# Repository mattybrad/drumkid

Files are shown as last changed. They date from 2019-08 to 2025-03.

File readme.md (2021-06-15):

# DrumKid
## Lo-fi aleatoric Arduino drum machine

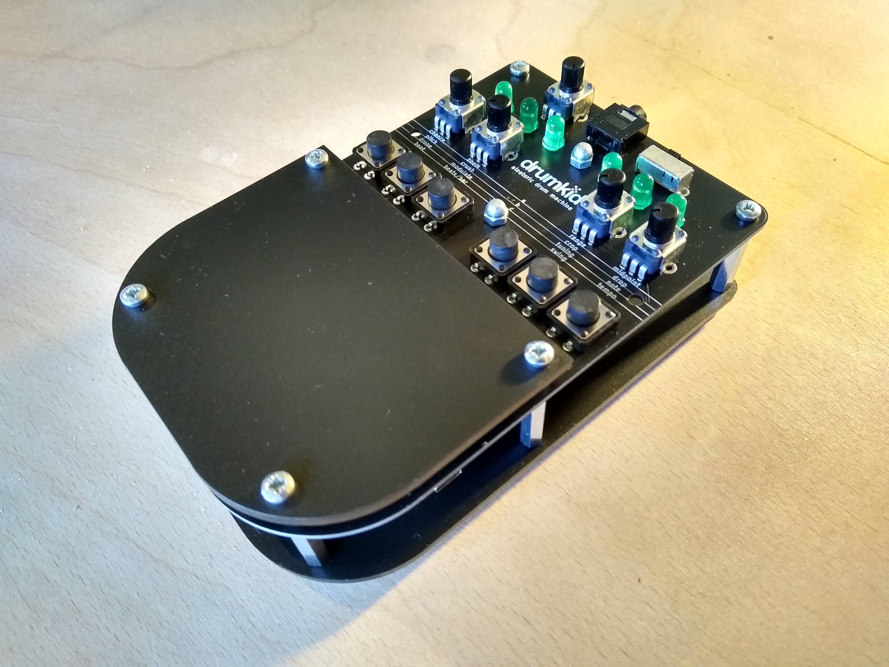
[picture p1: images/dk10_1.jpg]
DrumKid DrumKid (V10)


### Concept
A drum machine which generates rhythms using probability. Imagine a traditional step-based drum machine, but where various dice are rolled for each step, with the resulting numbers used to determine the behaviour of the beat.

### Buy Drumkid
You can buy Drumkid fully assembled or as a kit from <mattbradshawdesign.com>

### Setup
DrumKid is based around an Arduino Nano, and coded using the Arduino IDE. Audio is produced by the Mozzi library. You can build a version of DrumKid using an Arduino, a breadboard, and standard electronic components, or you can build/buy the "full" version described below.

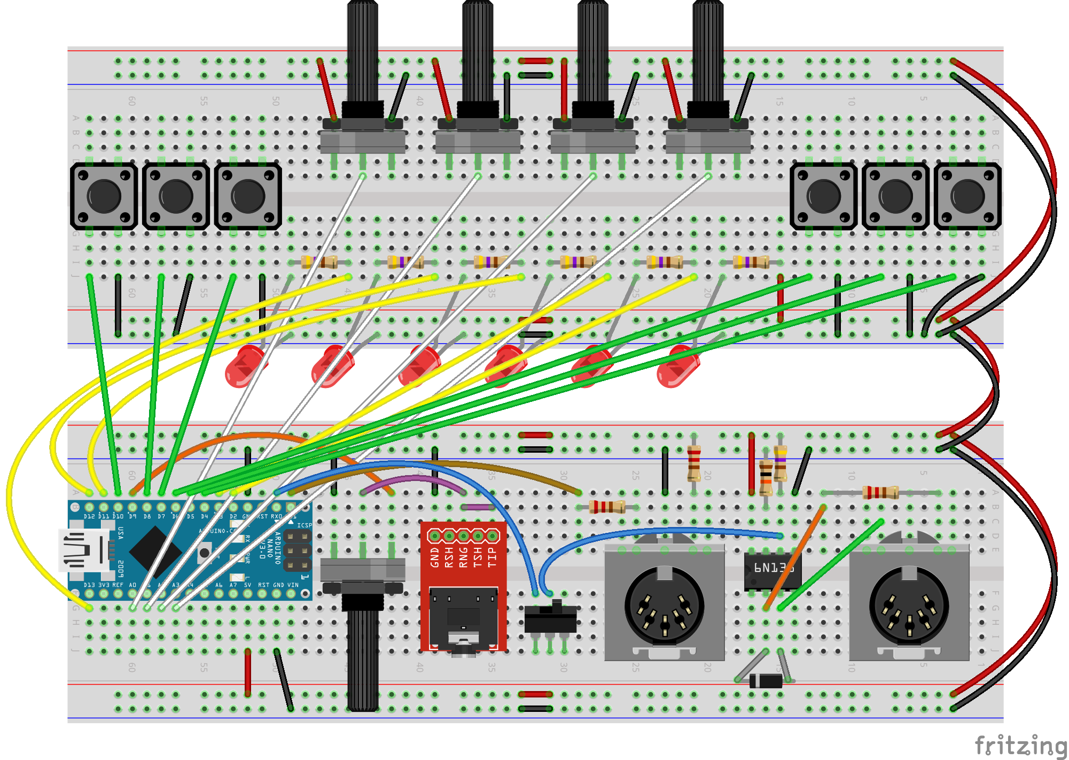
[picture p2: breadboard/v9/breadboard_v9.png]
Breadboard layout Breadboard layout (V9)


### Design
DrumKid is a portable, handheld, battery-powered instrument with a minimalist design. It consists of a PCB (printed circuit board) for the front panel, featuring knobs, buttons, LEDs, a power switch and a headphone/line output. The electronics are protected/enclosed by two laser-cut acrylic pieces and six metal standoffs.

### Open Source
This project is almost entirely open source. The code, breadboard layout, schematics, Gerber (PCB) files, and laser-cutter files are all included in the repository, with the aim of making this project easy to duplicate and adapt. Please note that the project depends on the Mozzi library, which is released under a Creative Commons non-commercial licence. I have used it here with kind permission from its creator, but please be aware that if you create a commercial product using this code, you will need to request permission from him. Go to <https://sensorium.github.io/Mozzi/> for more details.

### Versions
Versions 1-3 were early prototypes.

Version 4 was the first successful working design, with full code, schematics, Gerbers, etc available on GitHub.

Version 5 contained various PCB errors and has been superseded.

Versions 6 onwards were used in the final product, with version 10 being the latest at the time of writing.

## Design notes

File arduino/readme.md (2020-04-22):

# DrumKid Arduino code

While developing DrumKid, each new PCB version pretty much required its own new version of the code. Now that the project is nearing completion, I've reorganised the code as follows:

0.4 - this was the code for the V4 PCB
0.5 - this was the code for the V5 PCB
1.0 - this is the code for the V6 onwards

Unless you've got an old version of DrumKid, you should just refer to the latest version.

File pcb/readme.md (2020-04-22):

# PCB files

DrumKid is designed using KiCad. You can edit the KiCad files to produce a custom DrumKid PCB, or just use the Gerber files provided to order a DrumKid PCB from a manufacturer. The latest working, tested PCB is V6. V7 is coming soon with (very) minor revisions, and V8 might involve some surface-mount components because I've just learnt how to design/order pre-assembled boards.

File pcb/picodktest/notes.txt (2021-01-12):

change output resistors from 1K to 220R
label possible LED resistor values
include info about unused hacker pins

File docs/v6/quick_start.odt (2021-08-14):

Drumkid quick start guide

1) Insert batteries - unscrew the 6 thumbscrews on the back of Drumkid (you don't need a screwdriver), remove the back plate, and insert 3 AA batteries (rechargeable or regular). Alternatively, connect a USB mini cable to power the device. Carefully re-tighten the thumbscrews.

2) Connect audio - plug 3.5mm audio cable (mono or stereo) or a pair of headphones into the audio output.

3) Turn on and test - slide the power switch (top right on the front panel) from "0" to "1". The lights should flash briefly in a random pattern. Now press the "start/stop" button. The lights should flash in time to a drum beat, which you should be able to hear through the headphones.

4) Get to know the controls - try turning the "chance" control (the knob on the left) and the “midpoint” control (on the right). As long as “midpoint” is set high enough, you should hear more random drum hits as the “chance” parameter increases. Now try adjusting “zoom” and “range” to see what they do.

5) Try other parameters/effects - press the "B" button to switch to the second group of parameters. The knobs will now perform different functions. Try the left knob again - it will now change the pitch of the samples or make them play in reverse.

6) Randomise all the parameters - try pressing the A, B and D buttons simultaneously to generate a new random beat. Use these as a starting point to explore the different parameters.

7) Read the full manual online at mattbradshawdesign.com for detailed information about the different parameters, MIDI control, saving/loading sessions, troubleshooting, hacking Drumkid, etc.

If you have any problems, feel free to email me at

matthewloydbradshaw@gmail.com

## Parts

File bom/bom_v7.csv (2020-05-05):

Item | Quantity | Notes
DrumKid PCB | 1 | Not needed for breadboard version
Battery box (3xAA) | 1 | Not needed for breadboard version
Female header, 15x1 | 2 | Not needed for breadboard version
MIDI socket | 2
EG1206 slide switch (SPDT) | 2 | Not needed for breadboard version
DIP socket (8 pin) | 1 | Not needed for breadboard version
6N138 optoisolator | 1
1N5817 diode | 1
1N4148 diode | 1
Resistor (220) | 3
Resistor (470) | 1
Resistor (680) | 6
Resistor (10k) | 1
RK09K Potentiometer (10k linear taper) | 5 | Use breadboard compatible 10k pots for breadboard
LED (standard 5mm) | 6
Tayda A-853 stereo jack socket | 1 | Use breadboard-friendly 3.5mm jack socket for breadboard (or solder wires/header to standard 3.5mm socket)
12mm tactile push button (Wurth 430476085716) | 6
Electrolytic capacitor (470uF) | 2
Arduino Nano or compatible | 1
Laser-cut front panel cover (acrylic) | 1 | Not needed for breadboard version
Laser-cut rear panel (acrylic) | 1 | Not needed for breadboard version
M3 thumb screw (nylon, 10mm) | 8 | Not needed for breadboard version
M3 machine screw (6mm, pan head) | 4 | Not needed for breadboard version
M3 machine screw (10mm, pan head) | 2 | Not needed for breadboard version
M3 machine screw (10mm, countersunk head) | 2 | Not needed for breadboard version
M3 dome nut | 2 | Not needed for breadboard version
M3 hex nut | 4 | Not needed for breadboard version
M3xM3 standoff (female/female, 25mm) | 6 | Not needed for breadboard version
M3xM3 standoff (male/female, 5mm) | 4 | Not needed for breadboard version

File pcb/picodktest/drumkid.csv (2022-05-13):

Comment | Designator | Footprint | LCSC
Arduino_Nano_v3.x | A1 | Module:Arduino_Nano_WithMountingHoles
Battery | BT1 | Connector_Wire:SolderWirePad_1x02_P5.08mm_Drill1.5mm
470uF | C1,C3 | Capacitor_THT:CP_Radial_D6.3mm_P2.50mm
100nF | C2 | Capacitor_SMD:C_0402_1005Metric | C1525
22uF | C5 | Capacitor_SMD:C_0603_1608Metric | C59461
LED | D1,D2,D3,D4,D5,D6 | drumkidcustom:LED_D5.0mm
1N4148 | D7 | Diode_SMD:D_SOD-123 | C81598
1N5817 | D8 | Diode_SMD:D_SOD-123 | C727113
MountingHole | H1,H2,H3,H4,H5,H6,H7,H8,H9,H10 | drumkidcustom:MountingHole_3.2mm_M3
DIN-5_180degree | J1,J2 | drumkidcustom:MIDI_DIN5
Conn_01x15 | J10,J11 | Connector_PinHeader_2.54mm:PinHeader_1x15_P2.54mm_Vertical
Conn_01x05 | J12,J14 | Connector_PinSocket_2.54mm:PinSocket_1x05_P2.54mm_Vertical
Conn_01x15 | J3,J4 | Connector_PinSocket_2.54mm:PinSocket_1x15_P2.54mm_Vertical
Conn_01x10 | J5,J8 | Connector_PinSocket_2.54mm:PinSocket_1x10_P2.54mm_Vertical
Conn_01x10 | J6,J7 | Connector_PinHeader_2.54mm:PinHeader_1x10_P2.54mm_Vertical
AudioJack3_Ground_Switch | J9,J13,J15 | drumkidcustom:Tayda_3.5mm_stereo_TRS_jack_A-853
680 | R1,R2,R3,R4,R5,R6 | Resistor_SMD:R_0805_2012Metric | C17798
220 | R7,R10,R11,R12,R13 | Resistor_SMD:R_0805_2012Metric | C17557
270 | R14 | Resistor_SMD:R_0805_2012Metric | C17590
680 | R15 | Resistor_THT:R_Axial_DIN0207_L6.3mm_D2.5mm_P7.62mm_Horizontal
10k | R8 | Resistor_SMD:R_0805_2012Metric | C17414
470 | R9 | Resistor_SMD:R_0805_2012Metric | C17710
R_POT | RV1,RV2,RV3,RV4 | drumkidcustom:Potentiometer_Alps_RK09K_Single_Vertical
10k | RV5 | drumkidcustom:Potentiometer_Alps_RK09K_Single_Vertical
SW_SPDT | SW7,SW8 | drumkidcustom:EG1206
drumkid_logo | U2,U3 | drumkidcustom:drumkid_logo

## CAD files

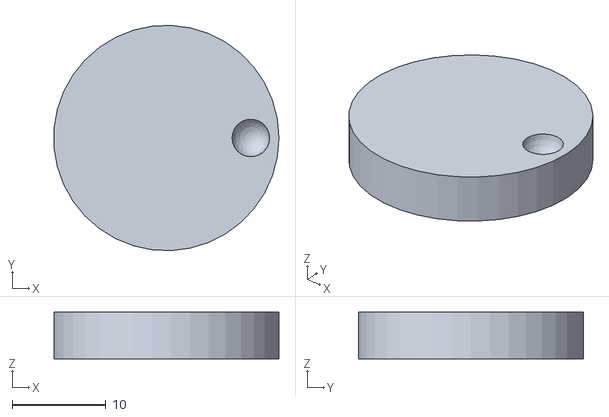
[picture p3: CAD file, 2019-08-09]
case/drumkid_knob.stl
24.0 x 24.0 x 5.00

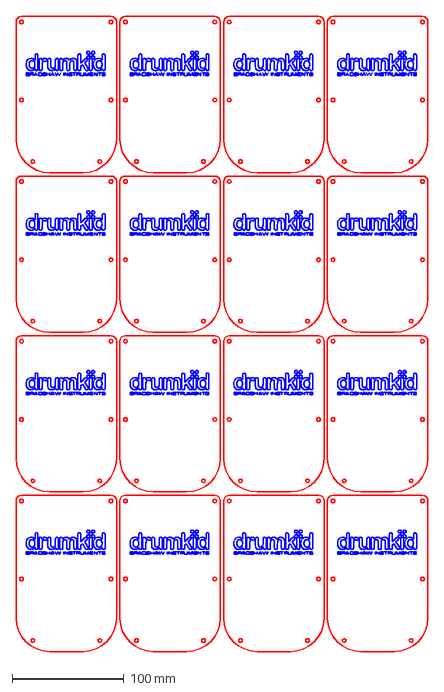
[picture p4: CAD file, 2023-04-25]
case/v6/drumkid laser parts 400x600 with bradshaw instruments text.dxf
369.0 x 569.0 mm

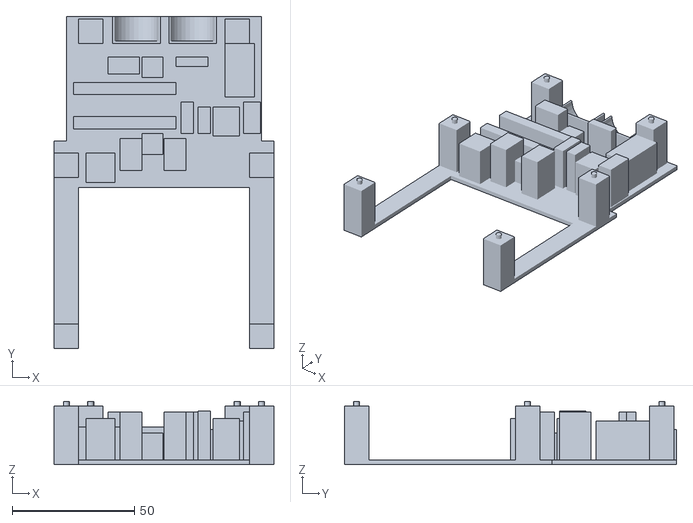
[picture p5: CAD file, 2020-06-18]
misc/jig/jig2.stl
90.0 x 136.0 x 26.0

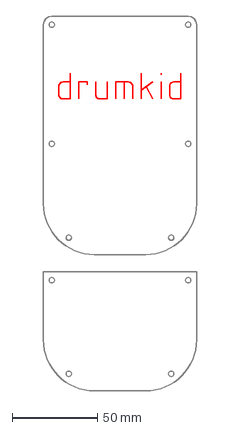
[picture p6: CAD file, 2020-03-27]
v6/case/drumkid laser parts.dxf
90.0 x 220.0 mm

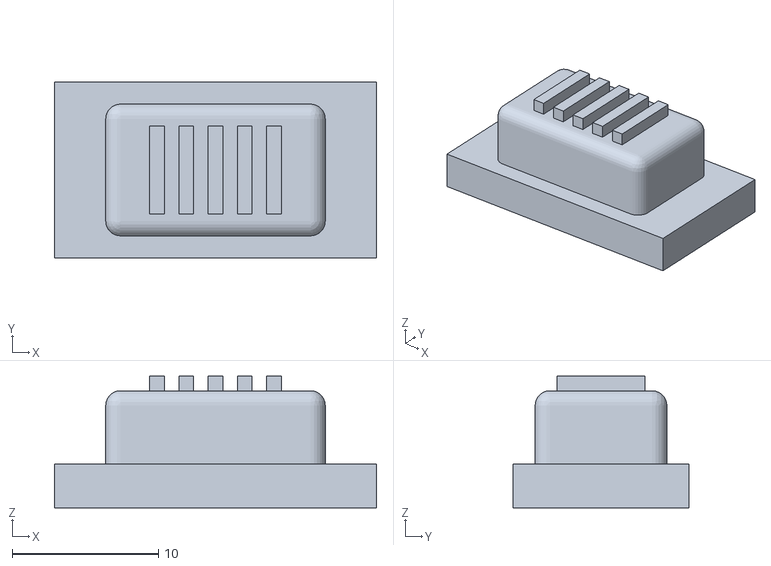
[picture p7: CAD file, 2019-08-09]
case/drumkid_switch.stl
22.0 x 12.0 x 9.00

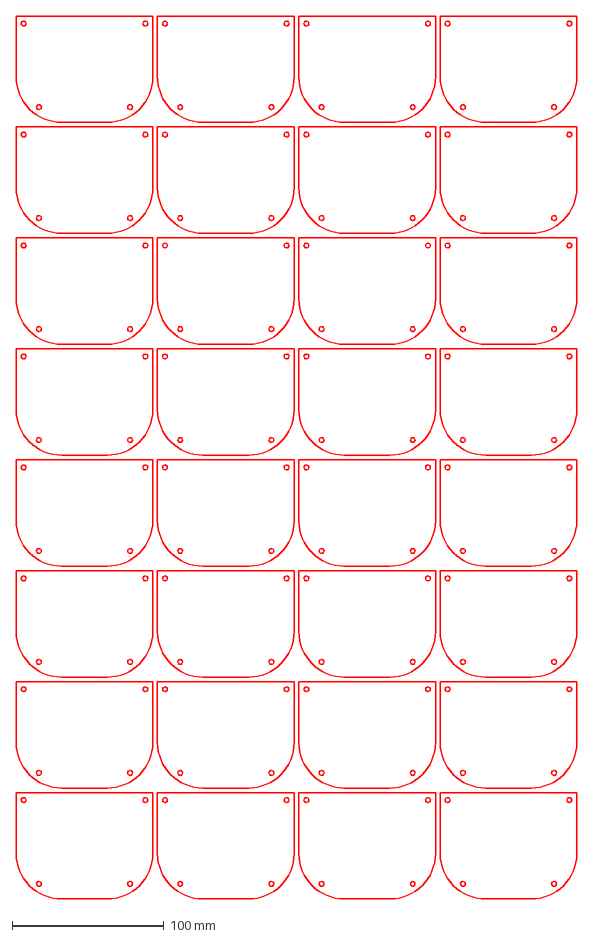
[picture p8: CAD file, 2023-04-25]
case/v6/drumkid front panel 400x600.dxf
369.0 x 581.0 mm

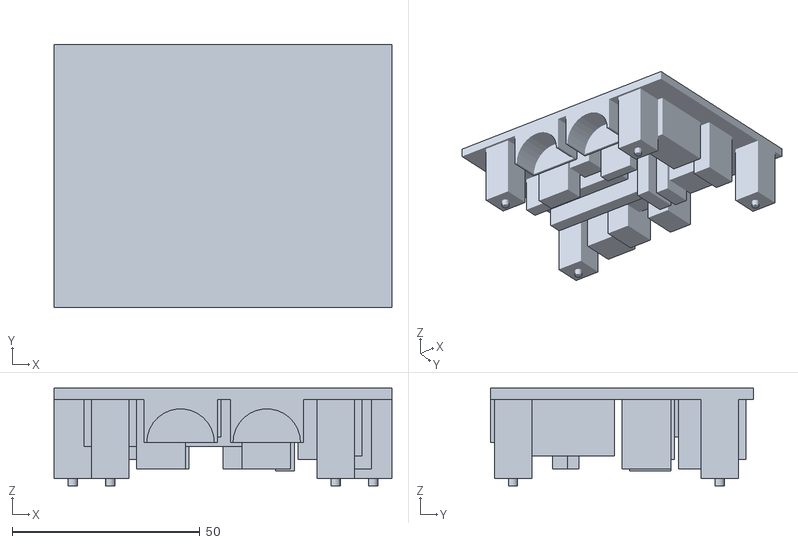
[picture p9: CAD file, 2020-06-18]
misc/jig/jig7.stl
90.0 x 70.0 x 26.0

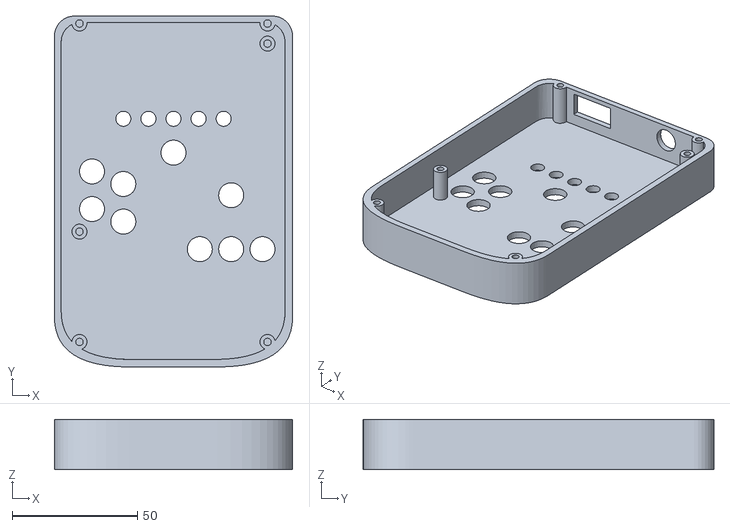
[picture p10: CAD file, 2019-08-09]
case/drumkid_case_top.stl
95.0 x 140.0 x 20.0

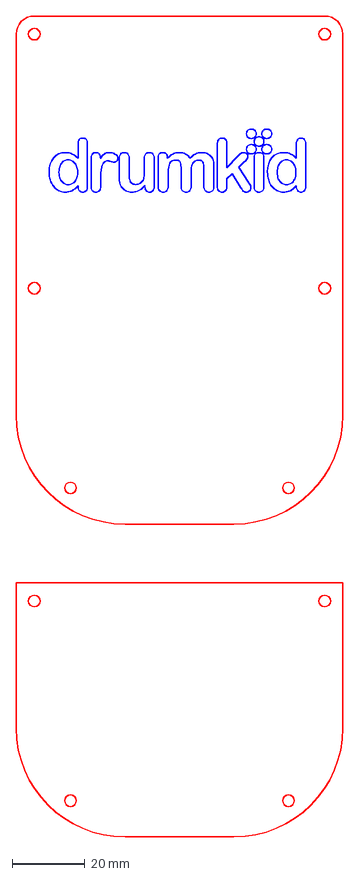
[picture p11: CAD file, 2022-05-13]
case/v6/drumkid laser parts april 22.dxf
90.0 x 226.2 mm

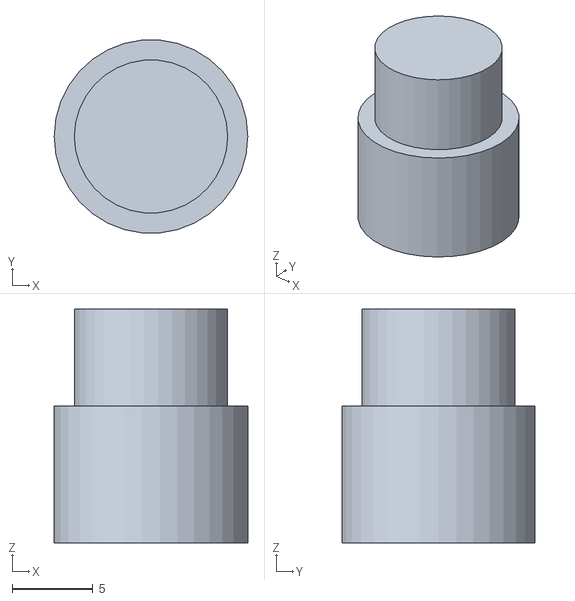
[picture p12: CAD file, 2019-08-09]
case/drumkid_button.stl
12.0 x 11.9 x 14.5

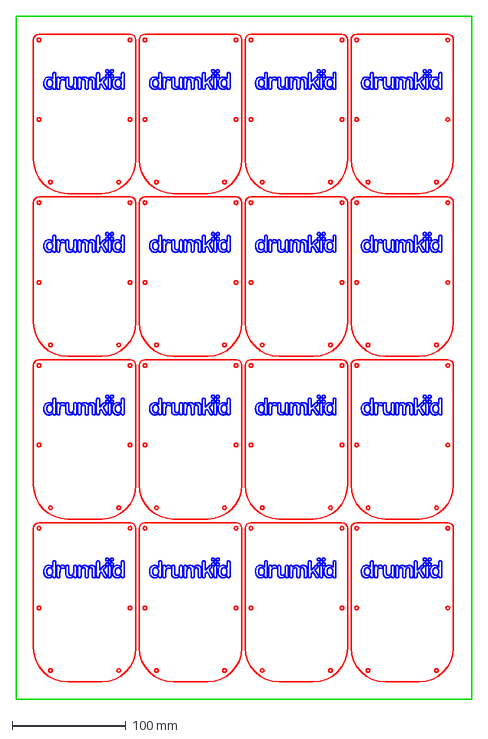
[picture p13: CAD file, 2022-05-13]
case/v6/drumkid laser parts 400x600 engrave only.dxf
400.0 x 600.0 mm

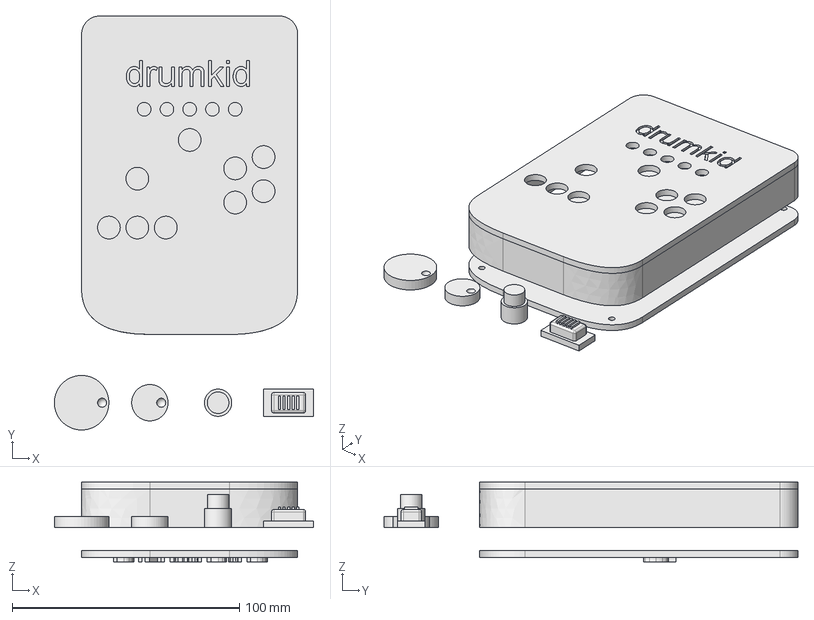
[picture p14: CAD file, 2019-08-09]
case/drumkid_case_1.FCStd
114.0 x 182.0 x 35.0 mm
middle x
bottom001
top with pcb mounts

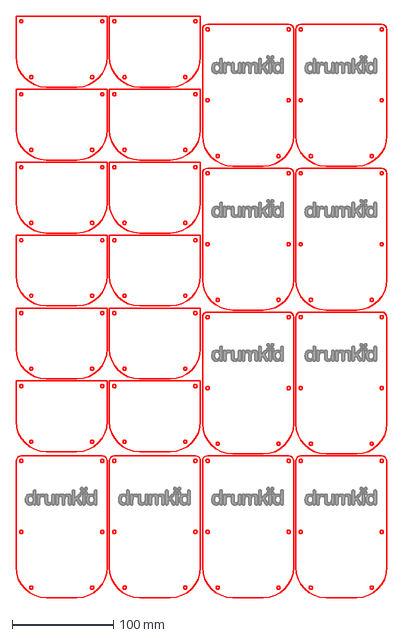
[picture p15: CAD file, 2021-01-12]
case/v6/drumkid laser parts 400x600.dxf
366.0 x 574.0 mm

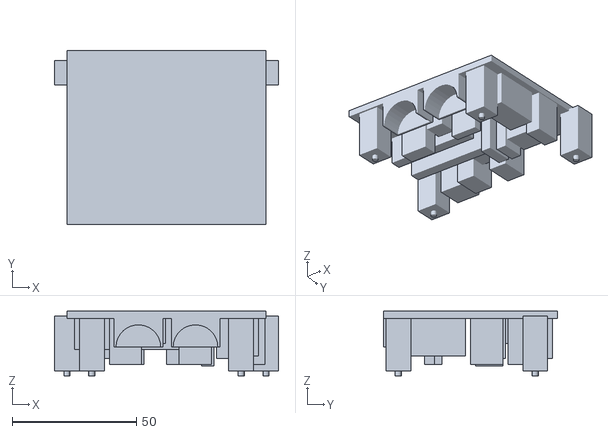
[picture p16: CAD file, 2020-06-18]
misc/jig/jig4.stl
90.0 x 70.0 x 26.0

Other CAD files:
misc/jig/jig6.stl
misc/jig/jig8.stl
case/drumkid_v3_cover.stl
case/v6/drumkid laser parts.dxf
case/drumkid cover laser 1.dxf
case/drumkid cover laser 2.dxf
case/drumkid laser parts v2.dxf
case/drumkid_case_bottom.stl
case/drumkid_knob_small.stl
case/v3 cover.FCStd
case/v4/archive/drumkid cover laser 1.dxf
case/v4/archive/drumkid cover laser 2.dxf
case/v4/archive/drumkid laser parts.dxf
case/v4/archive/drumkid_case_bottom.stl
case/v4/archive/drumkid_knob_small.stl
case/v4/archive/drumkid_v3_cover.stl
case/v4/archive/v3 cover.FCStd
case/v4/drumkid laser parts.dxf
case/v6/drumkid laser parts 600x600.dxf
misc/jig/jig.stl
misc/jig/jig3.stl
misc/jig/jig5.stl
misc/jig/jig9.stl
misc/jig/jig_underside.FCStd
misc/jig/testtri.ply

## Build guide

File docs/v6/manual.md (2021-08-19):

# DrumKid manual (V1.2)
## Introduction
Welcome to the DrumKid manual! DrumKid is a musical instrument that creates rhythms using random numbers. To get started with DrumKid, unscrew the six screws on the back of the unit (you should be able to do this by hand), and carefully remove the back plate. Insert three AA batteries (you can use rechargeable or single-use), replace the back plate, and tighten the screws. Slide the power switch to "on" - you should see the lights flash briefly. After this, DrumKid is ready to use. Plug some headphones or a 3.5mm stereo* aux cable into the socket, and start playing. If you would prefer not to use batteries, you can also power DrumKid by connecting a USB mini cable to the socket recessed on the right hand side of the device.

\* On newer DrumKid models (V8 or later) you can also use a mono 3.5mm cable, but this will not work on older models
## Philosophy
DrumKid is designed around a very basic computer chip with limited memory and processing power. My idea was to squeeze as much cool sound out of this chip as possible, but it has its limits. Rather than try and hide from these limits, I decided to embrace them. This means that it is absolutely possible to make horrible, distorted, broken noises using DrumKid. Some of these horrible noises will sound cool, others will not. DrumKid is a playable instrument like any other - experiment with it and see what happens.
## Demo videos and resources
You can find demo videos and other resources at https://www.mattbradshawdesign.com/projects/drumkid, or more technical info (source code, schematics, etc) at https://github.com/mattybrad/drumkid.
## Basic functions
DrumKid has six buttons and four knobs. The basic functions are as follows:
 - Press the start/stop button to start or stop the rhythm
 - Press buttons A/B/C/D to select different knob functions (see table below)
 - Turn any of the four knobs to alter the parameters in the current selected group (see table below)
 - Tap the tap tempo button repeatedly to set the tempo
 - Press buttons A+B together to load a session, then choose which session to load by pressing any of the buttons (or press multiple buttons together to cancel)
 - Press buttons C+D together to save a session, then choose which slot to save your session in by pressing any of the buttons (or press multiple buttons together to cancel)
 - Press buttons B+C together to change the current active memory bank, then choose a specific memory bank by pressing any of the buttons
## Other functions
DrumKid has a few extra hidden functions:
- Press buttons A+B+C together to reset your beat to default values. This will not affect any saved beats.
- Press buttons A+B+D together to generate a random beat. This will also not affect any saved beats.
- Press buttons B+C+D together to enter the MIDI settings menu (more details in the MIDI section of the manual)
## Presets
In the aleatoric spirit of DrumKid, all 36 sessions stored when you first use the instrument are randomly generated when DrumKid is built. Try loading a few of them to get a feel for what DrumKid can do.
## Parameters
There are 16 different parameters which can be adjusted on DrumKid, split into four groups, with each group's four parameters controlled by the four knobs. The parameters are grouped as follows:

### Group A (randomness)
 1. Chance
 2. Zoom
 3. Range
 4. Midpoint
### Group B (effects)
 1. Pitch
 2. Crush
 3. Crop
 4. Drop
### Group C (drone)
 1. Drone
 2. Modulate
 3. Tuning
 4. Note
### Group D (rhythm)
 1. Beat
 2. Beats/bar (time signature)
 3. Swing
 4. Tempo

You can try out each parameter by starting a rhythm (using the start/stop button), then selecting a group and turning the different knobs. For example, try selecting group B (by pressing the B button) then turning the first knob, which will now control "pitch". You should hear the sound change. Below are descriptions of exactly what each parameter does, and how it can be used.

**Chance** - The probability of extra drum hits being generated. At zero, the beat will be completely unchanged, while for higher values there will be lots of extra events, usually creating a busier, messier beat. This can be used in conjunction with zoom, midpoint, and range to create drum fills that transition organically from a simple beat.

**Zoom** - Chooses which subdivision of the beat should be affected by the randomly generated extra hits. When zoom is at zero, beats will only be generated for "whole notes" (i.e. the first beat of the bar). Higher values will affect half notes, quarter notes, eighth notes, and so on. A medium value is a good place to start for zoom, but turning it up can make a beat or fill sound more "urgent". Some of the smaller subdivisions will vary depending on the current "swing" setting.

**Range** - This is the range of velocities which will be assigned to the random hits, and works in conjunction with "midpoint" (see below). For all the random hits to have the same velocity as each other, keep this value at zero. For a wide range of velocities, turn this up high.

**Midpoint** - This is the average velocity of the randomly generated hits, and works in conjunction with "range". Note that this control does allow negative values (below halfway). If you set the midpoint to maximum and have range set at zero, all the randomly generated hits will be at max velocity. Conversely, if you set it at zero, some hits will be muted. Setting it somewhere in the middle (with non-zero range) will add some random hits while reducing the volume of others. Try keeping midpoint at a three-quarters setting to add a bustling undercurrent to your beat, or turn it up briefly to create a drum fill.

**Pitch** - Alters the playback speed of the samples. Will play samples backwards if you turn the knob below halfway.

**Crush** - Reduces the number of bits used to calculate the audio output, creating a digital distortion effect. Higher values are clean, lower values are more distorted (fewer bits).

**Crop** - Crops the end of the samples, creating a staccato effect. Lower values are more cropped.

**Drop** - This control mutes some or all of the drum channels, allowing you to quickly "drop" everything except the hi-hat and snare, for example, or only retain the kick drum. Broadly, this control has "treble-y" channels at one end and "bass-y" channels at the other. The setting corresponding to all the channels being audible is somewhere in the middle.

**Drone** - DrumKid generates a drone which can be mixed with the drum sounds. The "drone" parameter controls the amount of raw drone signal added to the mix. Turning to the left adds a single tone, while turning to the right adds two tones, a fifth apart. A halfway value mutes the drone.

**Modulation** - The drone can also used to modulate the audio signal from the drums, creating a robotic effect. When "modulation" is set at halfway, no effect is heard. Turning the knob to the left modulates the drums with a single drone, while turning it to the right modulates the drums with two tones, a fifth apart. Turning the knob all the way left or right creates an extreme effect, while values closer to halfway will be more subtle.

**Tuning** - Controls the overall tuning of the drones (both the single and fifth tones).

**Note** - Alter the root note of the drones, in semitone steps over an octave range.

**Beat** - Chooses between a series of basic underlying drum patterns (see "preset beat list" below).

**Beats/bar** - Alters the time signature of the beat, i.e. the number of steps in the pattern. You can have between 1 and 13 beats in a bar, or if you turn the knob all the way to the right, the time signature will be randomised at the start of each bar.

**Swing** - Creates a swing feel to a beat by altering the timing of certain hits. There are three settings: straight, partial swing, and full (triplet) swing.

**Tempo** - Alters the tempo (BPM) of the beat. Will override any tempo previously set using the tap tempo function. Has a range of 10BPM to ~1000BPM, with the "sensible" tempos grouped in the middle of the range.

## MIDI
DrumKid has MIDI in and out ports. These can be used to connect DrumKid to other MIDI equipment.

### Synchronisation
DrumKid sends and receives MIDI clock signals. A clock signal will be sent through the "MIDI out" socket whenever DrumKid is playing. If DrumKid detects a clock signal through the "MIDI in" socket, it will synchronise itself to this signal. Once a clock signal has been received, the tempo controls will stop having any effect until a clock "stop" command is received.

### Note output
By default, DrumKid outputs note data on channel 10 (the standard MIDI drum channel). The default note numbers are as follows:
- Kick - C1 (36)
- Click - C#1 (37)
- Snare - D1 (38)
- Closed hi-hat - F#1 (42)
- Tom - G1 (43)

### CC/note input
DrumKid responds to MIDI CC (control change) messages on any channel. DrumKid responds to CC numbers between 16 and 31, in order, as follows:
- Chance (CC 16)
- Zoom (CC 17)
- Range (CC 18)
- Midpoint (CC 19)
- Pitch (CC 20)
- Crush (CC 21)
- Crop (CC 22)
- Drop (CC 23)
- Drone (CC 24)
- Modulate (CC 25)
- Tuning (CC 26)
- Note (CC 27) (almost certainly better to just control this with regular note commands - see below)
- Beat (CC 28)
- Beats/bar (time signature) (CC 29)
- Swing (CC 30)
- Tempo (CC 31) (disabled when using sync)

You can also control the drone's base note using MIDI note commands on any channel.

### MIDI settings menu
If you press buttons B+C+D together, you can access the MIDI settings menu, which allows you to change the note and MIDI channel for each of the five drum channels used by DrumKid. Once you enter the menu, you can:
- Press any of the first five buttons (start/stop, A, B, C or D) to choose one of the five drum channels, or press the tap tempo button to exit the settings menu
- Once you have selected a drum, you can edit it as follows:
- Use the first two buttons (start/stop and A) to increase or decrease the MIDI note number
- Use the middle two buttons (B and C) to increase of decrease the MIDI channel
- Use button D to test the current note number and channel (i.e. send a MIDI note command with the new settings)
- Use the tap tempo button to confirm your selection and save it to DrumKid's memory. You will then have to enter the settings menu again using B+C+D if you want to change another drum channel
- At any time when in the MIDI settings menu, you can press all six buttons together to reset all MIDI settings to the defaults (see "note output" section above) - this will also exit the settings menu

## Other info
Because DrumKid uses a lo-fi method (known as pulse width modulation) to generate its audio signal, there is a trace, high-frequency noise present in the output. While this signal should be above the human range of hearing, you may want to filter it out if you are recording DrumKid in a studio, especially if you intend to pitch-shift the recording downwards (since this could bring the noise within human hearing range). To remove the noise, use a band-stop or low-pass filter (before any pitch-shifting) - the offending frequency should be at 32768Hz.

## Preset beat list
Please note that the LED pattern for each beat is illustrated to help you find the correct beat.
1. You can leave your hat on ⚫⚪⚪⚪⚪
2. Johnny Two-Hats ⚪⚫⚪⚪⚪
3. Drum lesson ⚪⚪⚫⚪⚪
4. Half-time rock ⚪⚪⚪⚫⚪
5. There there ⚪⚪⚪⚪⚫
6. Metal ⚫⚪⚪⚪⚪
7. Four to the floor ⚪⚫⚪⚪⚪
8. "Dance" ⚪⚪⚫⚪⚪
9. Blue Monday ⚪⚪⚪⚫⚪
10. Chime ⚪⚪⚪⚪⚫
11. Funk Soul Brother ⚫⚪⚪⚪⚪
12. Amen I ⚪⚫⚪⚪⚪
13. Amen II ⚪⚪⚫⚪⚪
14. Superstition ⚪⚪⚪⚫⚪
15. Derribar el muro ⚪⚪⚪⚪⚫
16. Hips don't lie ⚫⚪⚪⚪⚪
17. Videotape ⚪⚫⚪⚪⚪
18. Videotape (Bonnaroo) ⚪⚪⚫⚪⚪
19. Military ⚪⚪⚪⚫⚪
20. Ballad ⚪⚪⚪⚪⚫
21. Waltz ⚫⚪⚪⚪⚪
22. Take Five ⚪⚫⚪⚪⚪
23. Unsquare ⚪⚪⚫⚪⚪
24. Nihil ⚪⚪⚪⚫⚪

## Firmware versions
This manual refers to firmware version 1.2, which is now available and is included with newer DrumKids. Please note that updating to the new firmware from version 1.0 may alter some settings in your saved beats, particularly the time signature, tempo, and "drop" settings.

### Updating firmware
DrumKid's "brain" is a tiny computer called an Arduino Nano clone - this is the board inside DrumKid with a mini USB port on it. To upload new firmware, you will need a computer running the latest Arduino IDE software (download from https://www.arduino.cc/) and a USB "mini-B" cable to connect the computer to the Arduino Nano.

Before you upload anything to the Arduino, unplug any MIDI cables and make sure the switch on the underside of the PCB is set to "Arduino" rather than "MIDI" (and remember to switch it back to "MIDI" when you're done). You should also check that the "board", "processor" and "port" settings are correct in the Arduino software. Click on the "Tools" menu to check this:
- "Board" should be "Arduino Nano"
- "Port" will depend on your setup - try changing this if you're having trouble
- "Processor" should usually be "ATmega328P", but if this doesn't work then try "ATmega328P (Old Bootloader)"

To test that you're able to upload code, try opening the "Blink" example sketch (File > Examples > Basics > Blink) then uploading it to DrumKid (Sketch > Upload). If successful, one of the LEDs should start flashing on and off. Next, try uploading the latest DrumKid code from https://github.com/mattybrad/drumkid - start by downloading the whole project (repository) as a ZIP file, then unzip it to a folder on your computer, open the arduino/1.2/drumkid/drumkid.ino file (or a later version if it exists), and upload this sketch to the Arduino.

If you encounter any problems uploading code to the Arduino, check the following:
- The switch on the underside of the PCB should be set to "Arduino"
- Try (carefully) removing the Arduino Nano from DrumKid and uploading the "Blink" example sketch
- Try a different USB cable
- Double-check the "board" and "processor" settings (see above)
- Try a different port

## Using your own samples
You can upload your own samples using the online tool on the DrumKid web page: https://mattbradshawdesign.com/projects/drumkid/ - once you have downloaded the samples, copy them into your firmware folder and re-upload the firmware using the Arduino software. If you want to restore the default samples, you can either generate a new set of default samples using the web tool, or you can find a backup of them in the "originalsamples" folder.

## Hacking DrumKid (this section is a work in progress!)
DrumKid is an open source project, based on the Arduino Nano, and is designed in such a way that it can be modified and repaired. The source files for DrumKid are available from https://github.com/mattybrad/drumkid/ - you will find the schematics, CAD files, parts list, source code and more. The rest of this manual is aimed at advanced users of DrumKid who are already familiar with the instrument's basic features and would like to customise DrumKid (or for anyone who is just interested in how DrumKid works). Most ideas described in this part of the manual will require some skills in programming and/or electronics, but don't let that put you off - even if you don't currently have those skills, this might be a good way to learn!

### Disclaimer
The remainder of this manual will be a little less structured and a little more stream-of-consciousness. Also, I'll be referring to various files found in the GitHub repo, which is an ever-changing resource. If you can't find a particular file in the exact location specified, or if something is a bit different to what is described here, it probably just means that I've reorganised the repo or made some improvements to one of the files. You may occasionally need to use your imagination and/or ingenuity.

## What's possible?
Here are a few examples of things that you could do with DrumKid (beyond what's described in the vanilla manual above):
- Add your own preset beats
- Change the drone waveform
- Replace one of the parameters with an effect that you program yourself (e.g. delay or chorus)
- Add a light sensor to control certain parameters
- Add Eurorack CV control
- Make your own case in your favourite colour
- Mount DrumKid to a pedalboard or similar
- Build an enclosed wooden case for DrumKid
- 3D-print a custom case

## What's inside DrumKid?
The front panel of DrumKid is a printed circuit board (PCB), with some components mounted on top (buttons, knobs, LEDs, power switch, headphone output) and some hidden underneath. The stuff underneath is what we're mainly concerned with in this section of the manual. Besides the circuit board and electronic components, DrumKid also contains laser-cut plastic parts and metal stand-offs, which form a rudimentary (open-sided) case.

If you're only modifying DrumKid's software/code, you won't even need to do any disassembly, but it's useful to see and understand what you're modifying before you get stuck in. Unscrew the six thumb-screws on the back of DrumKid, and remove the rear cover (as if you were replacing the batteries). You should now be able to see all the circuitry, including the Arduino Nano board which controls everything.

The board inside DrumKid is actually technically not an official Arduino Nano, but an unofficial clone, so I will just call it a Nano from this point onwards. "Arduino" refers to a specific brand of boards, although the design is open source, which is how unofficial clones are able to exist legally. It was too costly to put an official Arduino board inside DrumKid, but I would heartily recommend buying an official Arduino to play with if you haven't used one before, or donating to the Arduino project.

Anyway, the Nano is a microcontroller - basically a small, low-powered computer. This computer runs a single "sketch", which is the name for a piece of software running on an Arduino (or compatible) board. This sketch monitors DrumKid's buttons and knobs, controls its LEDs, sends and receives data via the MIDI ports, and (most importantly) generates an audio signal.

Each of the Nano's pins (the metal bits along the edges) corresponds to a different signal either going into or out of the board, and there is a spare set of "breakout" holes that you can use to solder extra components which will connect to any of the pins. To access the other side of the board for soldering, simply unscrew the four machine screws on the front of DrumKid which hold the plastic cover in place.

## Hacking DrumKid's code
The basic process for hacking DrumKid's code starts the same way as installing a firmware update, so you should start by reading the "Updating Firmware" section above. You will see that I suggest uploading the "Blink" example sketch to check that the upload process is working properly. The next stage towards hacking DrumKid is to try editing that sketch. Try making the LED blink faster or slower, or try lighting a different LED. Have a look at some other example sketches. Maybe try and make certain LEDs light up when you press certain buttons. Below is a list of what each of the Nano's pins is used for in the circuit, to help you get started.

## Nano pins
The Nano board has 14 digital pins (which can either send or receive binary on/off signals) and 6 analogue pins (which can read a range of voltages between 0V and 5V). In DrumKid's circuit, the analogue pins are used to read the potentiometers, and the digital pins are used for everything else. Certain digital pins can also output a special kind of signal (PWM - pulse width modulation) which is useful for generating audio signals. Here is the list of pins used (and not used) by DrumKid:
D0 - MIDI input
D1 - MIDI output
D2 - LED 1
D3 - LED 2
D4 - Start/stop button
D5 - Button A
D6 - Button B
D7 - Button C
D8 - Button D
D9 - Audio output
D10 - Tap tempo button
D11 - LED 3
D12 - LED 4
D13 - LED 5
A0 - Potentiometer 1
A1 - Potentiometer 2
A2 - Potentiometer 3
A3 - Potentiometer 4
Please note there is also an LED (the left one) permanently connected to the 5V power supply - this is just to show you that DrumKid is receiving power, and cannot be controlled by the Nano.

## How DrumKid makes sound
To generate audio, DrumKid makes use of a library called Mozzi, which you can download from https://sensorium.github.io/Mozzi/

Mozzi makes efficient use of a microcontroller's limited resources, and is one of the few ways I have found of allowing an Arduino-style board to generate interesting sounds (beyond just square-wave bleeps). I would recommend trying the Mozzi example sketches once you've installed the library. Start with the basic sine wave example and check that you can hear a sound through the output, then try editing Mozzi sketches or writing your own to get familiar with how the library works.

## A simple first "hack" - editing the default rhythms
Once you're happy using the Arduino software to edit sketches and upload them to DrumKid, you can start editing the DrumKid source code. A good first task is to replace some of the default rhythms. Open the drumkid.ino file in your firmware folder, and you should see various tabs at the top of the window, representing other files besides the main code. Open the tab marked "beats.h".

You should see a lot of zeros and ones, organised into lines and blocks. Each line corresponds to a channel (kick, hi-hat, snare, rim, or tom, although obviously you can choose any samples you want). A line contains 32 ones or zeros. If you changed every 0 on the first line into a 1, the kick drum would be triggered 32 times over two bars. Your ones and zeros must be organised into groups of eight, like they are to start with (each group of eight is called a "byte" - computers like things to be in well-organised bytes). Each byte begins with the letter B, so that the software knows what to expect.

Try resetting an entire beat to just zeros, but then add a one at the start of the very first line (so the first byte is B10000000). Upload the code, use the "beat" control to find the beat you have created, and you should hear a very boring rhythm consisting of just one kick drum at the start of the bar.

Now make some more interesting beats. Remember you can always re-download the original beats from GitHub if you want them (or just make a copy of the beats.h file before you start editing).

## Interfacing DrumKid with other gear (Eurorack etc)
By default, DrumKid has an audio output, a MIDI output, and a MIDI input. This is already enough to connectivity to allow DrumKid to talk to a computer, and you may find that this is enough functionality for you, particularly if you are adept at using your DAW to re-map incoming MIDI signals. However, if you want to make DrumKid trigger a modular synth without using MIDI, for example... well, this topic is going to need some more in-depth thought and experimentation from me so I'm going to stop here for now. I did say it was a work in progress. More coming soon!

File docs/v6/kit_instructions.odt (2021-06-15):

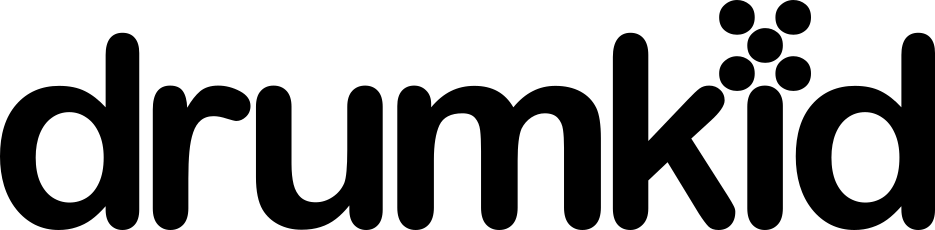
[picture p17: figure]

Kit assembly instructions

This guide will take you through the process of building your DrumKid step by step. If you are missing any components, or if you need any help with the assembly, please send me an email (matthewloydbradshaw@gmail.com).

Overview

Here's a quick list of the steps you're going to go through:

- Check parts
- Solder smaller components to the underside of the PCB
- Solder all components to the top side of the PCB
- Solder MIDI sockets and battery box leads to the underside of the PCB
- Insert the chips
- Insert batteries (if using them)
- Screw everything together
- Make music

Parts

Please check that your kit contains all of the following parts:

Component | Value/type | Quantity | Notes
Resistor | 220Ω | 5 | Red red brown gold
Resistor | 270Ω | 1 | Red purple brown gold
Resistor | 470Ω | 1 | Yellow purple brown gold
Resistor | 680Ω | 6 | Blue grey brown gold
Resistor | 10KΩ | 1 | Brown black orange gold
Diode | 1N4148 | 1 | Smaller diode
Diode | 1N5817 | 1 | Larger diode
Capacitor | 470µF | 2
Capacitor | 22µF | 1
Capacitor | 100nF | 1 | Marked “104”
Slide switch | | 2
Header | 15-pin female | 2
Audio socket | 3.5mm stereo | 1
Button | | 6
LED | | 6
Potentiometer | 10K linear | 5
MIDI socket | | 2
M3 thumb screws | 6mm, nylon | 6
IC socket | 8-pin | 1 | For optoisolator
Optoisolator | 6N138 | 1
Microcontroller | | 1 | Arduino Nano compatible
M3 machine screw | 6mm, pan head | 6
M3 machine screw | 10mm, countersunk | 2
M3 dome nut | | 2
M3 hex nut | | 2
M3 standoff (female/female) | 25mm | 6
M3 standoff (male/female) | 5mm | 4
Rear panel | | 1 | Larger plastic panel
Front panel | | 1 | Smaller plastic panel
DrumKid PCB | | 1
Battery box | 3xAA | 1

Soldering

DrumKid is designed to be relatively easy to solder. All of the components are "through-hole", which means that you poke the leads through the holes and then solder them in place on the other side, before trimming the leads if they stick out. The only aspect of DrumKid that is a little counter-intuitive is that some components are soldered on the front of the board, and some on the back. I’ve included some pictures to show where everything goes, and there are also some hints printed on the PCB itself.

One other thing that is potentially slightly confusing about DrumKid is that I have included some spaces on the PCB for extra components in case you want to customise your DrumKid in the future. Don't worry if you get to the end and find there are still holes with no components in them - that's normal!

If you're unsure about soldering, this online guide is a great place to start: https://learn.adafruit.com/adafruit-guide-excellent-soldering

I've found that the best way to assemble DrumKid is to start by soldering the components on the underside of the PCB (resistors, capacitors, etc), then solder the components on the top side (buttons, LEDs, etc), and finally flip the board back over to solder the last couple of chunky components on the underside. It's much easier if you solder everything roughly in order of size, starting with the smallest components. Here's the order in which I solder everything, along with some hints:

- Resistors (pay attention to the colours to make sure you get the right values, and bend the leads outwards to keep them in place)
- 1N4148 diode (be careful of the polarity - match the stripe to the stripe on the PCB)
- 1N5817 diode (again, careful of the polarity - match the stripe)
- IC socket (8-pin socket for the 6N138 chip)
- MIDI/Arduino switch (make sure the moveable part of the switch is nearest the outside of the board for easy access)
- Headers (15-pin sockets) for the Arduino (check the spacing matches the Arduino’s pins - use the middle of the three available rows on each side, start by soldering just one or two pins and get the headers properly aligned before soldering all the pins)
- Capacitors (careful of the polarity for the larger 470µF and 22µF capacitors – the white stripe on the capacitor lines up with the white half of the circle on the PCB)
- Flip the board over…
- Audio output (make sure it’s straight before soldering all the pins)
- Power switch
- Buttons
- LEDs (careful of the polarity - the long legs are positive) (also, it's a bit fiddly to get the LEDs aligned with each other - solder just the positive legs first to make it easier to realign the LEDs if needed)
- Potentiometers (these should snap into place)
- Flip the board back over again to solder the last couple of chunky components on the underside of the board…
- MIDI sockets (make sure they’re flush against the board and not wonky)
- Battery box leads (red is positive and black is negative)

At this stage, check that you don’t have any electrical components left over. If you do, solder them in place.

Assembly

Once you’re done with soldering, there are a few other steps before your drum machine is finished:

- Insert the 6N138 optoisolator (taking care not to bend the pins, and making sure the writing on the chip aligns with the label “6N138” on the PCB)
- Insert the Arduino Nano-compatible microcontroller (with the USB port nearest the edge of the PCB)
- Push the two countersunk screws through the bottom of the battery box from the inside (they should fit nicely into the two sloped holes), and tighten the two hexagonal nuts from the underside of the battery box (these nuts will act as spacers to keep the battery box lifted slightly above the component leads)
- Poke the two protruding ends of the battery box screws through the holes from the underside of the PCB, so that they stick out on the top side – you may want to loop the battery leads under the battery box to keep them out of the way
- Screw the two dome nuts onto the ends of the screws by hand, then tighten with a screwdriver to secure the battery box to the PCB
- Insert three AA batteries (if you are using them) or connect a USB lead, and check that the unit turns on and makes a sound when you press “start/stop” (make sure the volume is not turned down)
- If your unit is not working, check to see that everything is soldered correctly
- From the top side of the PCB, push the four shorter stand-offs (the things with a threaded hole in only one end) through the four lower-down holes (below the buttons) and screw them firmly into the longer stand-offs
- Again from the top side of the PCB, push two pan-head machine screws through the holes in the top-left and top-right corners and screw firmly into two long stand-offs
- Remove any plastic film from the two plastic panels
- Secure the smaller panel to the shorter stand-offs on the front of the board using pan-head machine screws
- Carefully secure the back panel using the six plastic thumb screws. You should tighten with your finger and thumb, not a screwdriver, and be careful not to force them – move them back and forth slightly until you find the thread, and don’t over-tighten them

Pictures (go to bit.ly/2TYxYdS for higher resolution colour versions)

A few pictures to show you roughly what you’re aiming for during assembly:

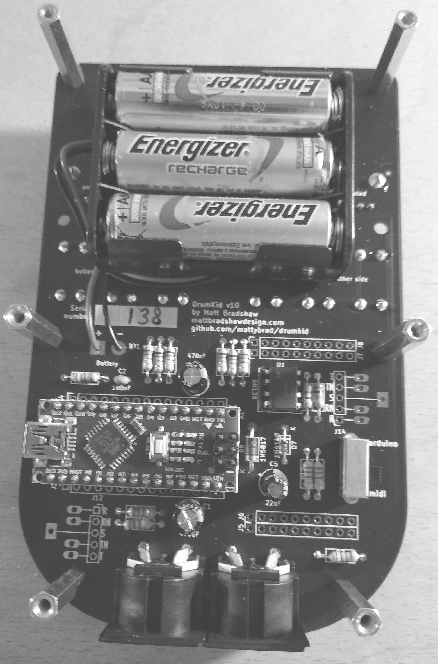
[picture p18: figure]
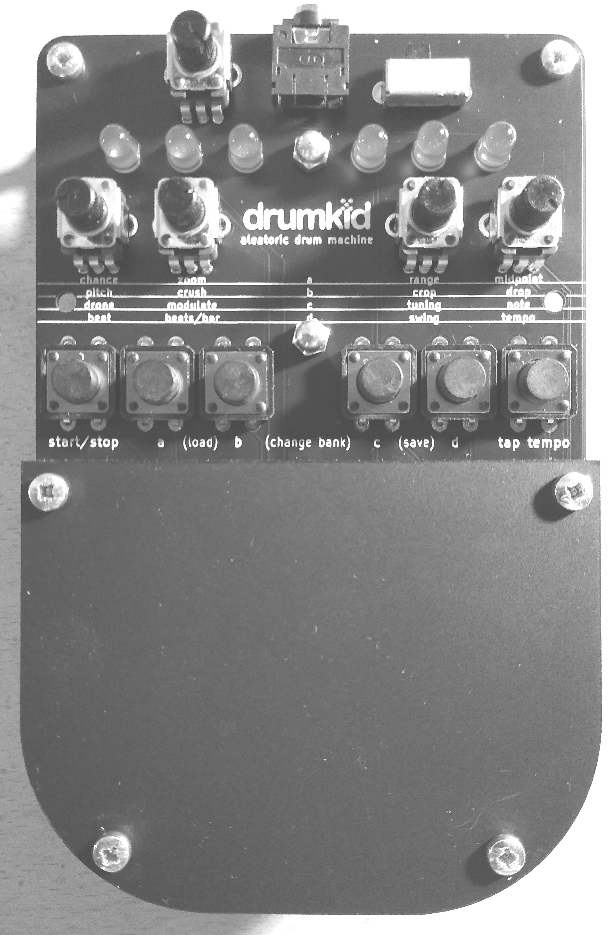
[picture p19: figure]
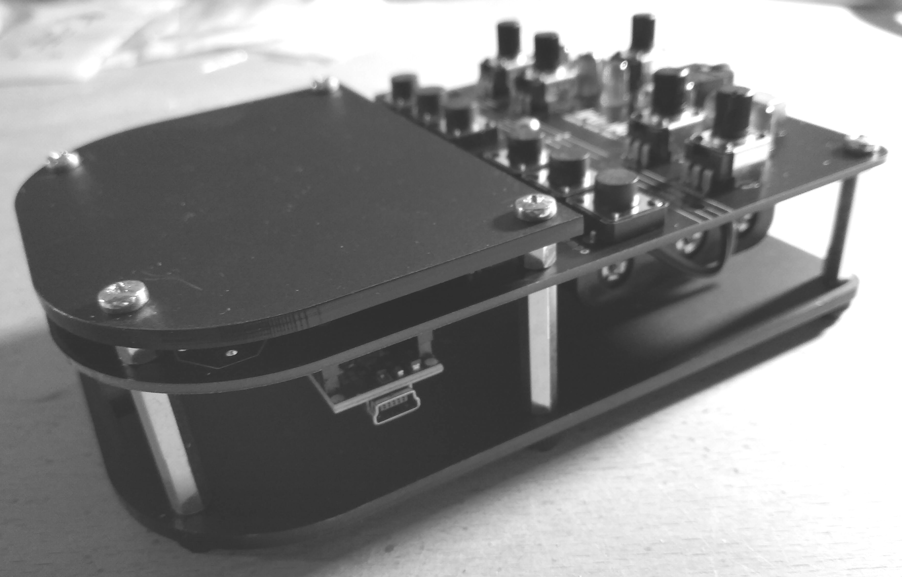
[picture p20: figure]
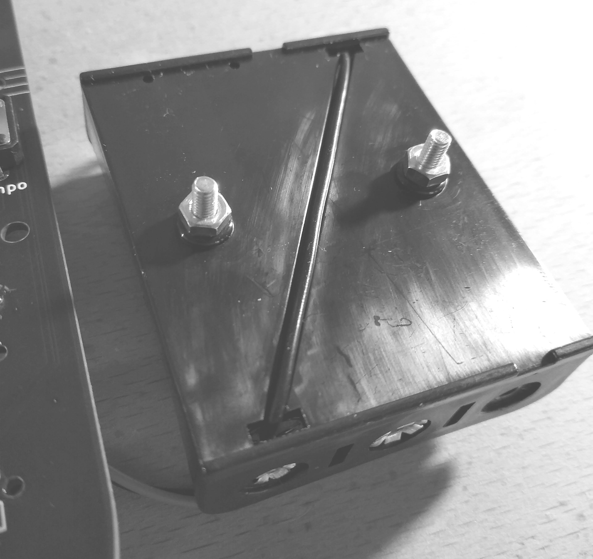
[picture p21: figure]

You should now have a finished, working drum machine. To read the main operating manual or to view a video tutorial, go to mattbradshawdesign.com/drumkid

Next steps – hacking…

If you’re interested in adding extra features to your DrumKid, you will notice that I have included extra spaces on the PCB. There are extra “breakout” rows for all of the Arduino Nano pins, footprints for two extra 3.5mm audio sockets, and some extra unconnected rows of pins, which I imagined could be a useful place to mount a small stripboard circuit. Additionally, I’ve include two M3 holes between the buttons and the potentiometers, which can either be used for mounting a larger extra circuit (perhaps in place of the battery box) or for mounting a small alternative front panel with different parameter labels, if you end up reprogramming the firmware. I’m aiming to make some videos of possible DrumKid hacks soon, so keep an eye on the website.

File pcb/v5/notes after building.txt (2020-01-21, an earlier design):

PROBLEMS WITH V5:
midi input causes buzz
	- 470uF decoupler on opto?
something not quite right about audio output, too bright? check
power LED not connected to, well, power
no labels for ICs
LEDs still slightly too bright?
labels for battery pos/neg DONE
silkscreen guide for led mounting

SOLUTIONS!
C3 and C7 were switched
1000uF cap on opto power largely solves noise
could also try 470uF on opto AND amp AND maybe atmega

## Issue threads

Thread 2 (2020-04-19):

compilation error in v4, missing mozzi_pgmspace.hs

dariosalvi78, 2020-04-19:
Trying your code on my Arduino UNO, it gives me:

/Applications/Arduino.app/Contents/Java/arduino-builder -dump-prefs -logger=machine -hardware /Applications/Arduino.app/Contents/Java/hardware -hardware /Users/aj6373/Library/Arduino15/packages -tools /Applications/Arduino.app/Contents/Java/tools-builder -tools /Applications/Arduino.app/Contents/Java/hardware/tools/avr -tools /Users/aj6373/Library/Arduino15/packages -built-in-libraries /Applications/Arduino.app/Contents/Java/libraries -libraries /Users/aj6373/Documents/Arduino/libraries -fqbn=arduino:avr:uno -vid-pid=0403_6001 -ide-version=10812 -build-path /var/folders/zr/lyn3n_j97zl69b3z7ngd94h1z2gtmf/T/arduino_build_52608 -warnings=all -build-cache /var/folders/zr/lyn3n_j97zl69b3z7ngd94h1z2gtmf/T/arduino_cache_617705 -prefs=build.warn_data_percentage=75 -prefs=runtime.tools.avrdude.path=/Users/aj6373/Library/Arduino15/packages/arduino/tools/avrdude/6.3.0-arduino17 -prefs=runtime.tools.avrdude-6.3.0-arduino17.path=/Users/aj6373/Library/Arduino15/packages/arduino/tools/avrdude/6.3.0-arduino17 -prefs=runtime.tools.avr-gcc.path=/Users/aj6373/Library/Arduino15/packages/arduino/tools/avr-gcc/7.3.0-atmel3.6.1-arduino5 -prefs=runtime.tools.avr-gcc-7.3.0-atmel3.6.1-arduino5.path=/Users/aj6373/Library/Arduino15/packages/arduino/tools/avr-gcc/7.3.0-atmel3.6.1-arduino5 -prefs=runtime.tools.arduinoOTA.path=/Users/aj6373/Library/Arduino15/packages/arduino/tools/arduinoOTA/1.3.0 -prefs=runtime.tools.arduinoOTA-1.3.0.path=/Users/aj6373/Library/Arduino15/packages/arduino/tools/arduinoOTA/1.3.0 -verbose /Users/aj6373/Downloads/drumkid-master/v4/arduino/drumkid/drumkid.ino
/Applications/Arduino.app/Contents/Java/arduino-builder -compile -logger=machine -hardware /Applications/Arduino.app/Contents/Java/hardware -hardware /Users/aj6373/Library/Arduino15/packages -tools /Applications/Arduino.app/Contents/Java/tools-builder -tools /Applications/Arduino.app/Contents/Java/hardware/tools/avr -tools /Users/aj6373/Library/Arduino15/packages -built-in-libraries /Applications/Arduino.app/Contents/Java/libraries -libraries /Users/aj6373/Documents/Arduino/libraries -fqbn=arduino:avr:uno -vid-pid=0403_6001 -ide-version=10812 -build-path /var/folders/zr/lyn3n_j97zl69b3z7ngd94h1z2gtmf/T/arduino_build_52608 -warnings=all -build-cache /var/folders/zr/lyn3n_j97zl69b3z7ngd94h1z2gtmf/T/arduino_cache_617705 -prefs=build.warn_data_percentage=75 -prefs=runtime.tools.avrdude.path=/Users/aj6373/Library/Arduino15/packages/arduino/tools/avrdude/6.3.0-arduino17 -prefs=runtime.tools.avrdude-6.3.0-arduino17.path=/Users/aj6373/Library/Arduino15/packages/arduino/tools/avrdude/6.3.0-arduino17 -prefs=runtime.tools.avr-gcc.path=/Users/aj6373/Library/Arduino15/packages/arduino/tools/avr-gcc/7.3.0-atmel3.6.1-arduino5 -prefs=runtime.tools.avr-gcc-7.3.0-atmel3.6.1-arduino5.path=/Users/aj6373/Library/Arduino15/packages/arduino/tools/avr-gcc/7.3.0-atmel3.6.1-arduino5 -prefs=runtime.tools.arduinoOTA.path=/Users/aj6373/Library/Arduino15/packages/arduino/tools/arduinoOTA/1.3.0 -prefs=runtime.tools.arduinoOTA-1.3.0.path=/Users/aj6373/Library/Arduino15/packages/arduino/tools/arduinoOTA/1.3.0 -verbose /Users/aj6373/Downloads/drumkid-master/v4/arduino/drumkid/drumkid.ino
Using board 'uno' from platform in folder: /Users/aj6373/Library/Arduino15/packages/arduino/hardware/avr/1.8.2
Using core 'arduino' from platform in folder: /Users/aj6373/Library/Arduino15/packages/arduino/hardware/avr/1.8.2
Detecting libraries used...
/Users/aj6373/Library/Arduino15/packages/arduino/tools/avr-gcc/7.3.0-atmel3.6.1-arduino5/bin/avr-g++ -c -g -Os -w -std=gnu++11 -fpermissive -fno-exceptions -ffunction-sections -fdata-sections -fno-threadsafe-statics -Wno-error=narrowing -flto -w -x c++ -E -CC -mmcu=atmega328p -DF_CPU=16000000L -DARDUINO=10812 -DARDUINO_AVR_UNO -DARDUINO_ARCH_AVR -I/Users/aj6373/Library/Arduino15/packages/arduino/hardware/avr/1.8.2/cores/arduino -I/Users/aj6373/Library/Arduino15/packages/arduino/hardware/avr/1.8.2/variants/standard /var/folders/zr/lyn3n_j97zl69b3z7ngd94h1z2gtmf/T/arduino_build_52608/sketch/drumkid.ino.cpp -o /dev/null
Alternatives for mozzi_pgmspace.h: []
In file included from /Users/aj6373/Downloads/drumkid-master/v4/arduino/drumkid/drumkid.ino:24:0:ResolveLibrary(mozzi_pgmspace.h)

  -> candidates: []/var/folders/zr/lyn3n_j97zl69b3z7ngd94h1z2gtmf/T/arduino_build_52608/sketch/MozziDK/tables/saw256_int8.h:9:10: fatal error: mozzi_pgmspace.h: No such file or directory

 #include "mozzi_pgmspace.h"
          ^~~~~~~~~~~~~~~~~~
compilation terminated.
exit status 1
Error compiling for board Arduino Uno.

dariosalvi78, 2020-04-19:
I overcame this manually by fixing the path of the lib.

Closed 2020-08-17.

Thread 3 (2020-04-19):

compilation error in v4: misssing Bounce2.h

dariosalvi78, 2020-04-19:
Arduino: 1.8.12 (Mac OS X), Board: "Arduino Uno"

/Applications/Arduino.app/Contents/Java/arduino-builder -dump-prefs -logger=machine -hardware /Applications/Arduino.app/Contents/Java/hardware -hardware /Users/aj6373/Library/Arduino15/packages -tools /Applications/Arduino.app/Contents/Java/tools-builder -tools /Applications/Arduino.app/Contents/Java/hardware/tools/avr -tools /Users/aj6373/Library/Arduino15/packages -built-in-libraries /Applications/Arduino.app/Contents/Java/libraries -libraries /Users/aj6373/Documents/Arduino/libraries -fqbn=arduino:avr:uno -vid-pid=0403_6001 -ide-version=10812 -build-path /var/folders/zr/lyn3n_j97zl69b3z7ngd94h1z2gtmf/T/arduino_build_52608 -warnings=all -build-cache /var/folders/zr/lyn3n_j97zl69b3z7ngd94h1z2gtmf/T/arduino_cache_617705 -prefs=build.warn_data_percentage=75 -prefs=runtime.tools.avrdude.path=/Users/aj6373/Library/Arduino15/packages/arduino/tools/avrdude/6.3.0-arduino17 -prefs=runtime.tools.avrdude-6.3.0-arduino17.path=/Users/aj6373/Library/Arduino15/packages/arduino/tools/avrdude/6.3.0-arduino17 -prefs=runtime.tools.avr-gcc.path=/Users/aj6373/Library/Arduino15/packages/arduino/tools/avr-gcc/7.3.0-atmel3.6.1-arduino5 -prefs=runtime.tools.avr-gcc-7.3.0-atmel3.6.1-arduino5.path=/Users/aj6373/Library/Arduino15/packages/arduino/tools/avr-gcc/7.3.0-atmel3.6.1-arduino5 -prefs=runtime.tools.arduinoOTA.path=/Users/aj6373/Library/Arduino15/packages/arduino/tools/arduinoOTA/1.3.0 -prefs=runtime.tools.arduinoOTA-1.3.0.path=/Users/aj6373/Library/Arduino15/packages/arduino/tools/arduinoOTA/1.3.0 -verbose /Users/aj6373/Downloads/drumkid-master/v4/arduino/drumkid/drumkid.ino
/Applications/Arduino.app/Contents/Java/arduino-builder -compile -logger=machine -hardware /Applications/Arduino.app/Contents/Java/hardware -hardware /Users/aj6373/Library/Arduino15/packages -tools /Applications/Arduino.app/Contents/Java/tools-builder -tools /Applications/Arduino.app/Contents/Java/hardware/tools/avr -tools /Users/aj6373/Library/Arduino15/packages -built-in-libraries /Applications/Arduino.app/Contents/Java/libraries -libraries /Users/aj6373/Documents/Arduino/libraries -fqbn=arduino:avr:uno -vid-pid=0403_6001 -ide-version=10812 -build-path /var/folders/zr/lyn3n_j97zl69b3z7ngd94h1z2gtmf/T/arduino_build_52608 -warnings=all -build-cache /var/folders/zr/lyn3n_j97zl69b3z7ngd94h1z2gtmf/T/arduino_cache_617705 -prefs=build.warn_data_percentage=75 -prefs=runtime.tools.avrdude.path=/Users/aj6373/Library/Arduino15/packages/arduino/tools/avrdude/6.3.0-arduino17 -prefs=runtime.tools.avrdude-6.3.0-arduino17.path=/Users/aj6373/Library/Arduino15/packages/arduino/tools/avrdude/6.3.0-arduino17 -prefs=runtime.tools.avr-gcc.path=/Users/aj6373/Library/Arduino15/packages/arduino/tools/avr-gcc/7.3.0-atmel3.6.1-arduino5 -prefs=runtime.tools.avr-gcc-7.3.0-atmel3.6.1-arduino5.path=/Users/aj6373/Library/Arduino15/packages/arduino/tools/avr-gcc/7.3.0-atmel3.6.1-arduino5 -prefs=runtime.tools.arduinoOTA.path=/Users/aj6373/Library/Arduino15/packages/arduino/tools/arduinoOTA/1.3.0 -prefs=runtime.tools.arduinoOTA-1.3.0.path=/Users/aj6373/Library/Arduino15/packages/arduino/tools/arduinoOTA/1.3.0 -verbose /Users/aj6373/Downloads/drumkid-master/v4/arduino/drumkid/drumkid.ino
Using board 'uno' from platform in folder: /Users/aj6373/Library/Arduino15/packages/arduino/hardware/avr/1.8.2
Using core 'arduino' from platform in folder: /Users/aj6373/Library/Arduino15/packages/arduino/hardware/avr/1.8.2
Detecting libraries used...
/Users/aj6373/Library/Arduino15/packages/arduino/tools/avr-gcc/7.3.0-atmel3.6.1-arduino5/bin/avr-g++ -c -g -Os -w -std=gnu++11 -fpermissive -fno-exceptions -ffunction-sections -fdata-sections -fno-threadsafe-statics -Wno-error=narrowing -flto -w -x c++ -E -CC -mmcu=atmega328p -DF_CPU=16000000L -DARDUINO=10812 -DARDUINO_AVR_UNO -DARDUINO_ARCH_AVR -I/Users/aj6373/Library/Arduino15/packages/arduino/hardware/avr/1.8.2/cores/arduino -I/Users/aj6373/Library/Arduino15/packages/arduino/hardware/avr/1.8.2/variants/standard /var/folders/zr/lyn3n_j97zl69b3z7ngd94h1z2gtmf/T/arduino_build_52608/sketch/drumkid.ino.cpp -o /dev/null
Alternatives for Bounce2.h: []drumkid:27:10: fatal error: Bounce2.h: No such file or directory

 #include <Bounce2.h>ResolveLibrary(Bounce2.h)

          ^~~~~~~~~~~
  -> candidates: []
compilation terminated.
exit status 1
Bounce2.h: No such file or directory

dariosalvi78, 2020-04-19:
OK I fixed this by importing the external library. I'll keep the issue open in case you want to add it to your repo or instruct how to fix itt.

mattybrad, 2020-07-07:
Thanks Dario - I ended up including Bounce.h in the repo to fix this

Closed 2020-07-07.

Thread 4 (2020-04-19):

cannot compile it

dariosalvi78, 2020-04-19:
after fixing the few issues, I get this:

Arduino: 1.8.12 (Mac OS X), Board: "Arduino Uno"

/Applications/Arduino.app/Contents/Java/arduino-builder -dump-prefs -logger=machine -hardware /Applications/Arduino.app/Contents/Java/hardware -hardware /Users/aj6373/Library/Arduino15/packages -tools /Applications/Arduino.app/Contents/Java/tools-builder -tools /Applications/Arduino.app/Contents/Java/hardware/tools/avr -tools /Users/aj6373/Library/Arduino15/packages -built-in-libraries /Applications/Arduino.app/Contents/Java/libraries -libraries /Users/aj6373/Documents/Arduino/libraries -fqbn=arduino:avr:uno -vid-pid=0403_6001 -ide-version=10812 -build-path /var/folders/zr/lyn3n_j97zl69b3z7ngd94h1z2gtmf/T/arduino_build_52608 -warnings=all -build-cache /var/folders/zr/lyn3n_j97zl69b3z7ngd94h1z2gtmf/T/arduino_cache_617705 -prefs=build.warn_data_percentage=75 -prefs=runtime.tools.avrdude.path=/Users/aj6373/Library/Arduino15/packages/arduino/tools/avrdude/6.3.0-arduino17 -prefs=runtime.tools.avrdude-6.3.0-arduino17.path=/Users/aj6373/Library/Arduino15/packages/arduino/tools/avrdude/6.3.0-arduino17 -prefs=runtime.tools.avr-gcc.path=/Users/aj6373/Library/Arduino15/packages/arduino/tools/avr-gcc/7.3.0-atmel3.6.1-arduino5 -prefs=runtime.tools.avr-gcc-7.3.0-atmel3.6.1-arduino5.path=/Users/aj6373/Library/Arduino15/packages/arduino/tools/avr-gcc/7.3.0-atmel3.6.1-arduino5 -prefs=runtime.tools.arduinoOTA.path=/Users/aj6373/Library/Arduino15/packages/arduino/tools/arduinoOTA/1.3.0 -prefs=runtime.tools.arduinoOTA-1.3.0.path=/Users/aj6373/Library/Arduino15/packages/arduino/tools/arduinoOTA/1.3.0 -verbose /Users/aj6373/Downloads/drumkid-master/v4/arduino/drumkid/drumkid.ino
/Applications/Arduino.app/Contents/Java/arduino-builder -compile -logger=machine -hardware /Applications/Arduino.app/Contents/Java/hardware -hardware /Users/aj6373/Library/Arduino15/packages -tools /Applications/Arduino.app/Contents/Java/tools-builder -tools /Applications/Arduino.app/Contents/Java/hardware/tools/avr -tools /Users/aj6373/Library/Arduino15/packages -built-in-libraries /Applications/Arduino.app/Contents/Java/libraries -libraries /Users/aj6373/Documents/Arduino/libraries -fqbn=arduino:avr:uno -vid-pid=0403_6001 -ide-version=10812 -build-path /var/folders/zr/lyn3n_j97zl69b3z7ngd94h1z2gtmf/T/arduino_build_52608 -warnings=all -build-cache /var/folders/zr/lyn3n_j97zl69b3z7ngd94h1z2gtmf/T/arduino_cache_617705 -prefs=build.warn_data_percentage=75 -prefs=runtime.tools.avrdude.path=/Users/aj6373/Library/Arduino15/packages/arduino/tools/avrdude/6.3.0-arduino17 -prefs=runtime.tools.avrdude-6.3.0-arduino17.path=/Users/aj6373/Library/Arduino15/packages/arduino/tools/avrdude/6.3.0-arduino17 -prefs=runtime.tools.avr-gcc.path=/Users/aj6373/Library/Arduino15/packages/arduino/tools/avr-gcc/7.3.0-atmel3.6.1-arduino5 -prefs=runtime.tools.avr-gcc-7.3.0-atmel3.6.1-arduino5.path=/Users/aj6373/Library/Arduino15/packages/arduino/tools/avr-gcc/7.3.0-atmel3.6.1-arduino5 -prefs=runtime.tools.arduinoOTA.path=/Users/aj6373/Library/Arduino15/packages/arduino/tools/arduinoOTA/1.3.0 -prefs=runtime.tools.arduinoOTA-1.3.0.path=/Users/aj6373/Library/Arduino15/packages/arduino/tools/arduinoOTA/1.3.0 -verbose /Users/aj6373/Downloads/drumkid-master/v4/arduino/drumkid/drumkid.ino
Using board 'uno' from platform in folder: /Users/aj6373/Library/Arduino15/packages/arduino/hardware/avr/1.8.2
Using core 'arduino' from platform in folder: /Users/aj6373/Library/Arduino15/packages/arduino/hardware/avr/1.8.2
Detecting libraries used...
/Users/aj6373/Library/Arduino15/packages/arduino/tools/avr-gcc/7.3.0-atmel3.6.1-arduino5/bin/avr-g++ -c -g -Os -w -std=gnu++11 -fpermissive -fno-exceptions -ffunction-sections -fdata-sections -fno-threadsafe-statics -Wno-error=narrowing -flto -w -x c++ -E -CC -mmcu=atmega328p -DF_CPU=16000000L -DARDUINO=10812 -DARDUINO_AVR_UNO -DARDUINO_ARCH_AVR -I/Users/aj6373/Library/Arduino15/packages/arduino/hardware/avr/1.8.2/cores/arduino -I/Users/aj6373/Library/Arduino15/packages/arduino/hardware/avr/1.8.2/variants/standard /var/folders/zr/lyn3n_j97zl69b3z7ngd94h1z2gtmf/T/arduino_build_52608/sketch/drumkid.ino.cpp -o /dev/null
Alternatives for Bounce2.h: [Bounce2@2.53]
ResolveLibrary(Bounce2.h)
  -> candidates: [Bounce2@2.53]
/Users/aj6373/Library/Arduino15/packages/arduino/tools/avr-gcc/7.3.0-atmel3.6.1-arduino5/bin/avr-g++ -c -g -Os -w -std=gnu++11 -fpermissive -fno-exceptions -ffunction-sections -fdata-sections -fno-threadsafe-statics -Wno-error=narrowing -flto -w -x c++ -E -CC -mmcu=atmega328p -DF_CPU=16000000L -DARDUINO=10812 -DARDUINO_AVR_UNO -DARDUINO_ARCH_AVR -I/Users/aj6373/Library/Arduino15/packages/arduino/hardware/avr/1.8.2/cores/arduino -I/Users/aj6373/Library/Arduino15/packages/arduino/hardware/avr/1.8.2/variants/standard -I/Users/aj6373/Documents/Arduino/libraries/Bounce2/src /var/folders/zr/lyn3n_j97zl69b3z7ngd94h1z2gtmf/T/arduino_build_52608/sketch/drumkid.ino.cpp -o /dev/null
Alternatives for EEPROM.h: [EEPROM@2.0]
ResolveLibrary(EEPROM.h)
  -> candidates: [EEPROM@2.0]
/Users/aj6373/Library/Arduino15/packages/arduino/tools/avr-gcc/7.3.0-atmel3.6.1-arduino5/bin/avr-g++ -c -g -Os -w -std=gnu++11 -fpermissive -fno-exceptions -ffunction-sections -fdata-sections -fno-threadsafe-statics -Wno-error=narrowing -flto -w -x c++ -E -CC -mmcu=atmega328p -DF_CPU=16000000L -DARDUINO=10812 -DARDUINO_AVR_UNO -DARDUINO_ARCH_AVR -I/Users/aj6373/Library/Arduino15/packages/arduino/hardware/avr/1.8.2/cores/arduino -I/Users/aj6373/Library/Arduino15/packages/arduino/hardware/avr/1.8.2/variants/standard -I/Users/aj6373/Documents/Arduino/libraries/Bounce2/src -I/Users/aj6373/Library/Arduino15/packages/arduino/hardware/avr/1.8.2/libraries/EEPROM/src /var/folders/zr/lyn3n_j97zl69b3z7ngd94h1z2gtmf/T/arduino_build_52608/sketch/drumkid.ino.cpp -o /dev/null
Using cached library dependencies for file: /Users/aj6373/Documents/Arduino/libraries/Bounce2/src/Bounce2.cpp
Generating function prototypes...
/Users/aj6373/Library/Arduino15/packages/arduino/tools/avr-gcc/7.3.0-atmel3.6.1-arduino5/bin/avr-g++ -c -g -Os -w -std=gnu++11 -fpermissive -fno-exceptions -ffunction-sections -fdata-sections -fno-threadsafe-statics -Wno-error=narrowing -flto -w -x c++ -E -CC -mmcu=atmega328p -DF_CPU=16000000L -DARDUINO=10812 -DARDUINO_AVR_UNO -DARDUINO_ARCH_AVR -I/Users/aj6373/Library/Arduino15/packages/arduino/hardware/avr/1.8.2/cores/arduino -I/Users/aj6373/Library/Arduino15/packages/arduino/hardware/avr/1.8.2/variants/standard -I/Users/aj6373/Documents/Arduino/libraries/Bounce2/src -I/Users/aj6373/Library/Arduino15/packages/arduino/hardware/avr/1.8.2/libraries/EEPROM/src /var/folders/zr/lyn3n_j97zl69b3z7ngd94h1z2gtmf/T/arduino_build_52608/sketch/drumkid.ino.cpp -o /var/folders/zr/lyn3n_j97zl69b3z7ngd94h1z2gtmf/T/arduino_build_52608/preproc/ctags_target_for_gcc_minus_e.cpp
/Applications/Arduino.app/Contents/Java/tools-builder/ctags/5.8-arduino11/ctags -u --language-force=c++ -f - --c++-kinds=svpf --fields=KSTtzns --line-directives /var/folders/zr/lyn3n_j97zl69b3z7ngd94h1z2gtmf/T/arduino_build_52608/preproc/ctags_target_for_gcc_minus_e.cpp
Compiling sketch...
/Users/aj6373/Library/Arduino15/packages/arduino/tools/avr-gcc/7.3.0-atmel3.6.1-arduino5/bin/avr-g++ -c -g -Os -Wall -Wextra -std=gnu++11 -fpermissive -fno-exceptions -ffunction-sections -fdata-sections -fno-threadsafe-statics -Wno-error=narrowing -MMD -flto -mmcu=atmega328p -DF_CPU=16000000L -DARDUINO=10812 -DARDUINO_AVR_UNO -DARDUINO_ARCH_AVR -I/Users/aj6373/Library/Arduino15/packages/arduino/hardware/avr/1.8.2/cores/arduino -I/Users/aj6373/Library/Arduino15/packages/arduino/hardware/avr/1.8.2/variants/standard -I/Users/aj6373/Documents/Arduino/libraries/Bounce2/src -I/Users/aj6373/Library/Arduino15/packages/arduino/hardware/avr/1.8.2/libraries/EEPROM/src /var/folders/zr/lyn3n_j97zl69b3z7ngd94h1z2gtmf/T/arduino_build_52608/sketch/drumkid.ino.cpp -o /var/folders/zr/lyn3n_j97zl69b3z7ngd94h1z2gtmf/T/arduino_build_52608/sketch/drumkid.ino.cpp.o
In file included from /var/folders/zr/lyn3n_j97zl69b3z7ngd94h1z2gtmf/T/arduino_build_52608/sketch/MozziDK/MozziGuts.h:23:0,
                 from /Users/aj6373/Downloads/drumkid-master/v4/arduino/drumkid/drumkid.ino:18:
/var/folders/zr/lyn3n_j97zl69b3z7ngd94h1z2gtmf/T/arduino_build_52608/sketch/MozziDK/hardware_defines.h:21:14: warning: this use of "defined" may not be portable [-Wexpansion-to-defined]
 #if !(IS_AVR() || IS_TEENSY3() || IS_STM32() || IS_ESP8266() || IS_SAMD21())
              ^
/var/folders/zr/lyn3n_j97zl69b3z7ngd94h1z2gtmf/T/arduino_build_52608/sketch/MozziDK/hardware_defines.h:21:30: warning: this use of "defined" may not be portable [-Wexpansion-to-defined]
 #if !(IS_AVR() || IS_TEENSY3() || IS_STM32() || IS_ESP8266() || IS_SAMD21())
                              ^
/var/folders/zr/lyn3n_j97zl69b3z7ngd94h1z2gtmf/T/arduino_build_52608/sketch/MozziDK/hardware_defines.h:21:30: warning: this use of "defined" may not be portable [-Wexpansion-to-defined]
/var/folders/zr/lyn3n_j97zl69b3z7ngd94h1z2gtmf/T/arduino_build_52608/sketch/MozziDK/hardware_defines.h:21:30: warning: this use of "defined" may not be portable [-Wexpansion-to-defined]
/var/folders/zr/lyn3n_j97zl69b3z7ngd94h1z2gtmf/T/arduino_build_52608/sketch/MozziDK/hardware_defines.h:21:30: warning: this use of "defined" may not be portable [-Wexpansion-to-defined]
/var/folders/zr/lyn3n_j97zl69b3z7ngd94h1z2gtmf/T/arduino_build_52608/sketch/MozziDK/hardware_defines.h:21:30: warning: this use of "defined" may not be portable [-Wexpansion-to-defined]
/var/folders/zr/lyn3n_j97zl69b3z7ngd94h1z2gtmf/T/arduino_build_52608/sketch/MozziDK/hardware_defines.h:21:44: warning: this use of "defined" may not be portable [-Wexpansion-to-defined]
 #if !(IS_AVR() || IS_TEENSY3() || IS_STM32() || IS_ESP8266() || IS_SAMD21())
                                            ^
/var/folders/zr/lyn3n_j97zl69b3z7ngd94h1z2gtmf/T/arduino_build_52608/sketch/MozziDK/hardware_defines.h:21:44: warning: this use of "defined" may not be portable [-Wexpansion-to-defined]
/var/folders/zr/lyn3n_j97zl69b3z7ngd94h1z2gtmf/T/arduino_build_52608/sketch/MozziDK/hardware_defines.h:21:44: warning: this use of "defined" may not be portable [-Wexpansion-to-defined]
/var/folders/zr/lyn3n_j97zl69b3z7ngd94h1z2gtmf/T/arduino_build_52608/sketch/MozziDK/hardware_defines.h:21:44: warning: this use of "defined" may not be portable [-Wexpansion-to-defined]
/var/folders/zr/lyn3n_j97zl69b3z7ngd94h1z2gtmf/T/arduino_build_52608/sketch/MozziDK/hardware_defines.h:21:44: warning: this use of "defined" may not be portable [-Wexpansion-to-defined]
/var/folders/zr/lyn3n_j97zl69b3z7ngd94h1z2gtmf/T/arduino_build_52608/sketch/MozziDK/hardware_defines.h:21:44: warning: this use of "defined" may not be portable [-Wexpansion-to-defined]
/var/folders/zr/lyn3n_j97zl69b3z7ngd94h1z2gtmf/T/arduino_build_52608/sketch/MozziDK/hardware_defines.h:21:44: warning: this use of "defined" may not be portable [-Wexpansion-to-defined]
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
dariosalvi78, 2020-04-19:
OK, also this was fixed by importing Mozzi (latest release). It compiles at least!

dariosalvi78, 2020-04-19:
after compiling it, it runs, but I can't hear anything interesting. It emits sounds, and they look rhythmic, but nothing that resembles what you show in the video. BTW, I am trying this on an Arduino UNO and a breadboard, using the schema described in this repo (v4).

I'll do some more tests and see. It would be really nice to replicate this: my aim was to build it for my daughter so that she can learn some electronic music.

All the best.

mattybrad, 2020-07-07:
Hey Dario, really sorry I only just saw your issues - I've never had a GitHub repo that people actually interacted with before so I hadn't set up any notifications! I've done lots of updates since this - hopefully you might have better luck now :)

dariosalvi78, 2020-07-07:
thanks Matt. I'll try it and see if I can make it work.

Closed 2020-07-07.

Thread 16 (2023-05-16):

Drumkid on rampart

poetaster, 2023-05-16:
I just wanted to send you a note that I've been playing with drum kid on https://github.com/poetaster/rampart which is designed for CV input on analog 4-7 ... since I only have 3 buttons in that layout it's limited. I also have a euclidean patterns program in the works. In any case, thanks for sharing the code ;)

poetaster, 2023-06-13:
> That’s nice
>
> just got into the world of ae modular, i’m really curious about rampart. what are you doing with the drumkid in there? Since all is midi, i’m curious about what possibilities the cv is offering. thanks for sharing

I haven't applied CV in the drumkid context yet but have a number of patches like:
https://github.com/poetaster/rampart/blob/master/WavePacket_PDreso-nano/WavePacket_PDreso-nano.ino

which do. I started using this with my own analog auto synth (keep aka. moat) which was a response to Bastl labs Kastle mini-modular.  rampart has worked relatively well (given how primitive I kept it) with keep, kastle 1.5 and the korg micromodular.

I have a euclidean rythms sampler built with axoloti, rather on the high end, and I wanted  to create  a low-fi version of that. I have a self built one, but drum kid is much, much better ;)

In any case, the CV, given appropriate scaling can do just about anything continuous or otherwise :) Usually, I use it as a continuous function to something like fiter Q or cutoff.

julientaq, 2023-06-13:
got any info on the moat keep? can’t find anything.

that said, it looks like it would pair nicely with a nanosynth ns1 https://www.sound-machines.it/product/ns1nanosynth/

julientaq, 2023-06-13:
oh yeah. forgot to say.

i love my drumkid. a lovely piece of gear.

poetaster, 2023-06-13:
> got any info on the moat keep? can’t find anything.
>
> that said, it looks like it would pair nicely with a nanosynth ns1 https://www.sound-machines.it/product/ns1nanosynth/

https://github.com/poetaster/moat it's a project not a product :) I have some fast and dirty sound examples at: https://poetaster.de/synths/

And the ns1 is a nice piece of kit :)

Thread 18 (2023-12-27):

Only first half of default rhythms is played

jordanlev, 2023-12-27:
When I make edits to the default rhythms in the “beats.h” file (as suggested in the “A simple first hack” section of the manual), it seems that only the first half (16 beats) are actually played by DrumKid. Whatever I put in for beats 17-32 are ignored and only Beats 1-16 are looped.

Oddly, the NUM_BEATS definition at the top of that file is set to 24… so I’m not sure what that does. (I tried changing that number to 32, but didn’t affect behavior).

Thanks for any help you can provide.

 -Jordan

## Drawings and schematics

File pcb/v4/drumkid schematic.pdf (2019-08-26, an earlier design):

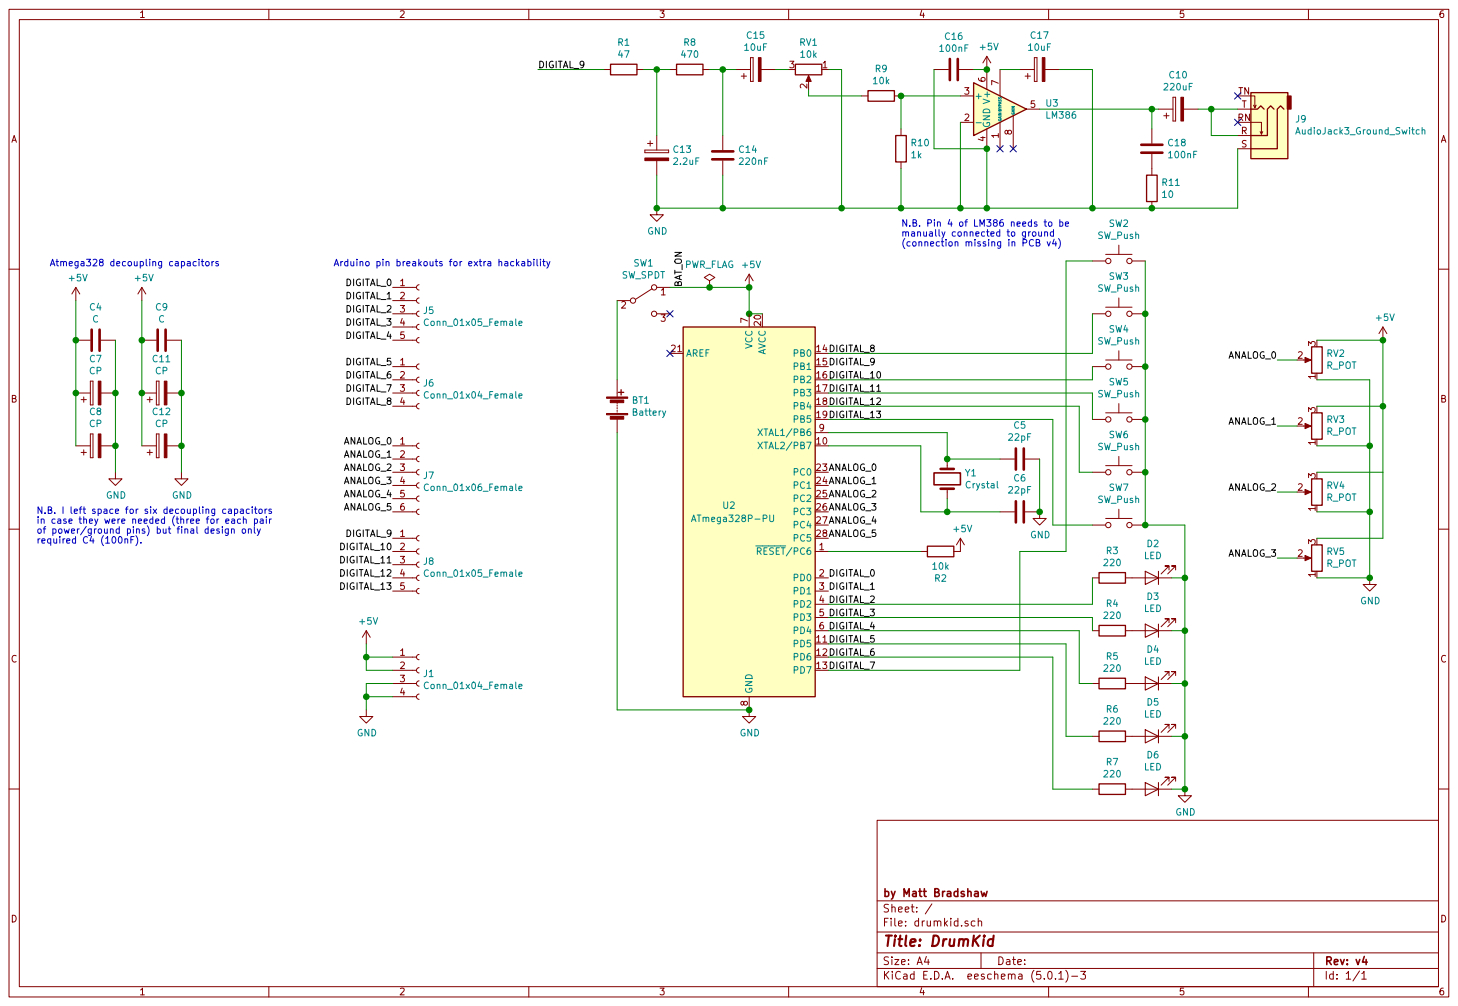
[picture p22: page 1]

3 RV5 R_POT ANALOG_3 N.B. Pin 4 of LM386 needs to be manually connected to ground
(connection missing in PCB v4)

N.B. I left space for six decoupling capacitors
in case they were needed (three for each pair
of power/ground pins) but final design only
required C4 (100nF).

File: drumkid.sch Sheet: / by Matt Bradshaw

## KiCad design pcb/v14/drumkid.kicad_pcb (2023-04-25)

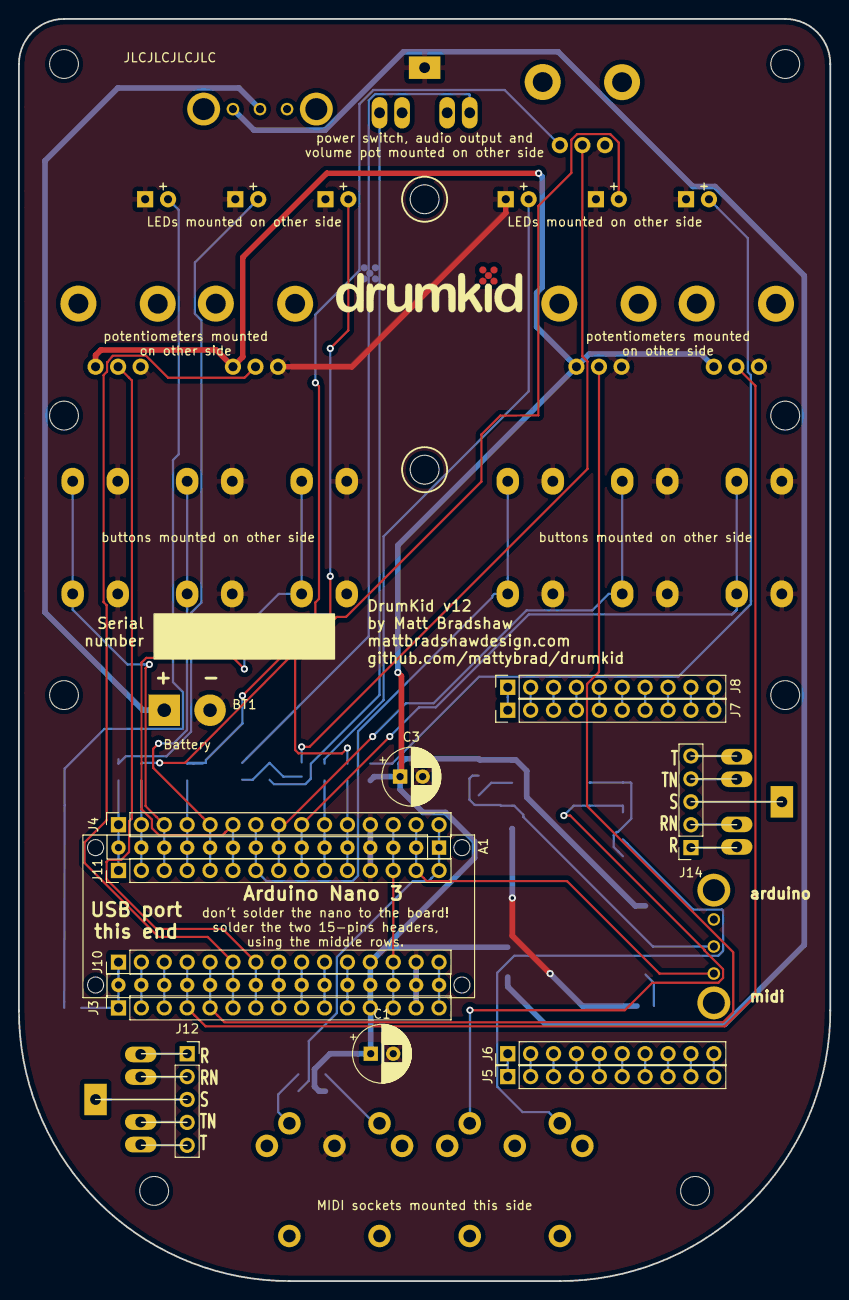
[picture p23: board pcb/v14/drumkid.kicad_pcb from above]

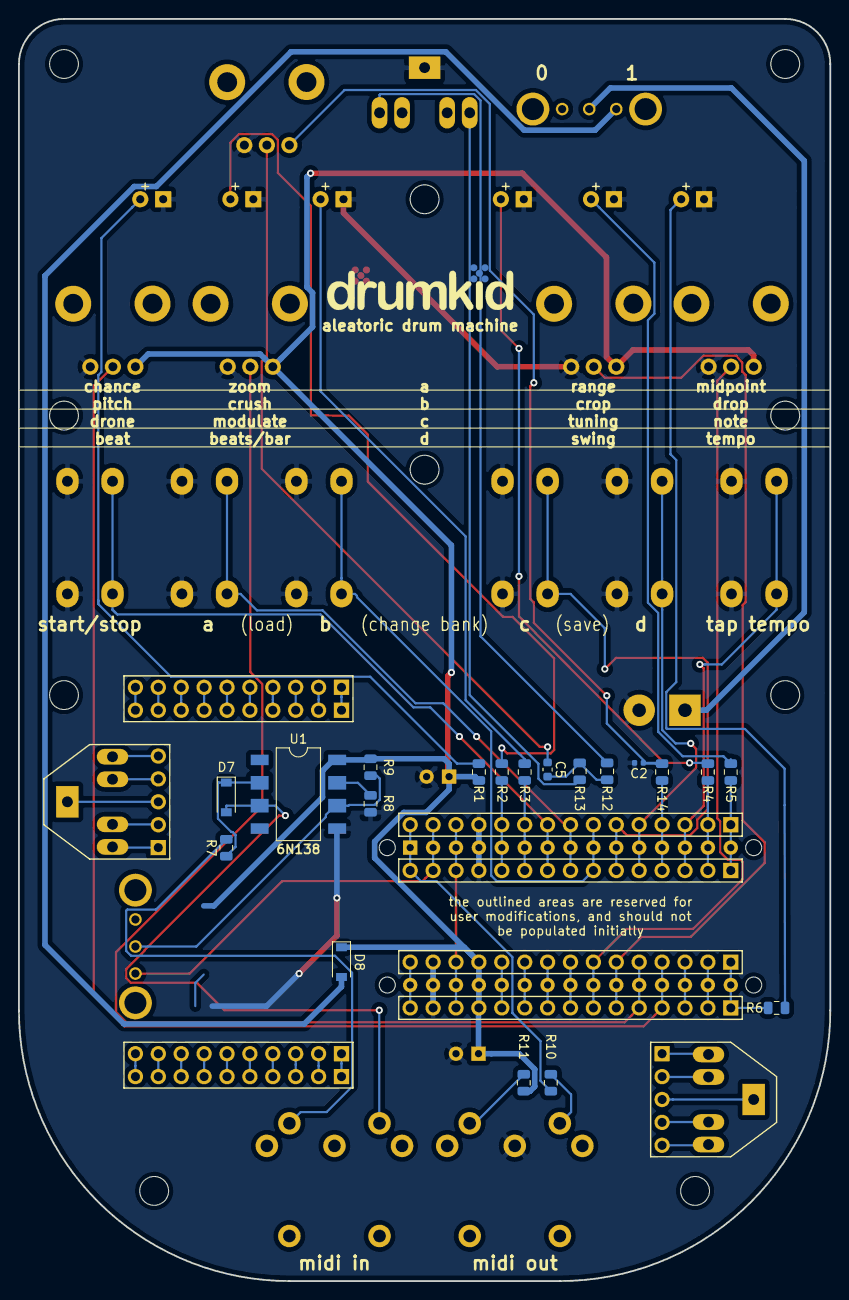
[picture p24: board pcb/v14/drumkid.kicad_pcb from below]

Board: 2 copper layers, 90.0 x 140.0 mm, 69 parts (41 on the bottom side), 78 nets.

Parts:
A1: Arduino_Nano_v3.x; Arduino_Nano_WithMountingHoles
BT1: Battery; SolderWirePad_1x02_P5.08mm_Drill1.5mm
C1, C3: 470uF; CP_Radial_D6.3mm_P2.50mm
C2: 100nF; C_0402_1005Metric
C5: 22uF; C_0603_1608Metric
D1, D2, D3, D4, D5, D6: LED; LED_D5.0mm
D7: 1N4148; D_SOD-123
D8: 1N5817; D_SOD-123
H1, H2, H3, H4, H5, H6, H7, H8, H9, H10: MountingHole; MountingHole_3.2mm_M3
J1, J2: DIN-5_180degree; MIDI_DIN5
J3, J4: Conn_01x15; PinSocket_1x15_P2.54mm_Vertical
J5, J8: Conn_01x10; PinSocket_1x10_P2.54mm_Vertical
J6, J7: Conn_01x10; PinHeader_1x10_P2.54mm_Vertical
J9, J13, J15: AudioJack3_Ground_Switch; Tayda_3.5mm_stereo_TRS_jack_A-853
J10, J11: Conn_01x15; PinHeader_1x15_P2.54mm_Vertical
J12, J14: Conn_01x05; PinSocket_1x05_P2.54mm_Vertical
R1, R2, R3, R4, R5, R6: 680; R_0805_2012Metric
R7, R10, R11, R12, R13: 220; R_0805_2012Metric
R8: 10k; R_0805_2012Metric
R9: 470; R_0805_2012Metric
R14: 270; R_0805_2012Metric
RV1, RV2, RV3, RV4: R_POT; Potentiometer_Alps_RK09K_Single_Vertical
RV5: 10k; Potentiometer_Alps_RK09K_Single_Vertical
SW1, SW2, SW3, SW4, SW5, SW6: SW_Push; SW_PUSH-12mm_Wuerth-430476085716
SW7, SW8: SW_SPDT; EG1206
U1: 6N138; PowerIntegrations_SMD-8
U2, U3: drumkid_logo

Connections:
+9V: A1.30, J3.15, J10.15
/3V3: A1.17, J3.2, J10.2
/ANALOG_0: A1.19, J3.4, J10.4, RV1.2
/ANALOG_1: A1.20, J3.5, J10.5, RV2.2
/ANALOG_2: A1.21, J3.6, J10.6, RV3.2
/ANALOG_3: A1.22, J3.7, J10.7, RV4.2
/ANALOG_4: A1.23, J3.8, J10.8
/ANALOG_5: A1.24, J3.9, J10.9
/ANALOG_6: A1.25, J3.10, J10.10
/ANALOG_7: A1.26, J3.11, J10.11
/AREF: A1.18, J3.3, J10.3
/DIGITAL_0: A1.2, J4.14, J11.14, SW8.1
/DIGITAL_1: A1.1, J4.15, J11.15, R10.2
/DIGITAL_2: A1.5, J4.11, J11.11, R2.2
/DIGITAL_3: A1.6, J4.10, J11.10, R3.2
/DIGITAL_4: A1.7, J4.9, J11.9, SW1.1
/DIGITAL_5: A1.8, J4.8, J11.8, SW2.1
/DIGITAL_6: A1.9, J4.7, J11.7, SW3.1
/DIGITAL_7: A1.10, J4.6, J11.6, SW4.1
/DIGITAL_8: A1.11, J4.5, J11.5, SW5.1
/DIGITAL_9: A1.12, J4.4, J11.4, R14.2
/DIGITAL_10: A1.13, J4.3, J11.3, SW6.1
/DIGITAL_11: A1.14, J4.2, J11.2, R4.2
/DIGITAL_12: A1.15, J4.1, J11.1, R5.2
/DIGITAL_13: A1.16, J3.1, J10.1, R6.2
/RESET: A1.3, A1.28, J3.13, J4.13, J10.13, J11.13
GND: A1.4, A1.29, BT1.2, C1.2, C2.2, C3.2, D1.1, D2.1, D3.1, D4.1, D5.1, D6.1, J2.2, J3.14, J4.12, J9.S, J10.14, J11.12, R8.1, RV1.3, RV2.3, RV3.3, RV4.3, RV5.3, SW1.2, SW2.2, SW3.2, SW4.2, SW5.2, SW6.2, U1.5
unnamed: BT1.1, SW7.2
unnamed: C2.1, R14.1, RV5.1
unnamed: C5.1, RV5.2
unnamed: C5.2, R12.2, R13.2
unnamed: D1.2, R1.1
unnamed: D2.2, R2.1
unnamed: D3.2, R3.1
unnamed: D4.2, R4.1
unnamed: D5.2, R5.1
unnamed: D6.2, R6.1
unnamed: D7.1, R7.1, U1.2
unnamed: D7.2, J1.5, U1.3
unnamed: D8.2, SW7.1
unnamed: J1.4, R7.2
unnamed: J2.4, R11.1
unnamed: J2.5, R10.1
unnamed: J5.1, J6.1
unnamed: J5.2, J6.2
unnamed: J5.3, J6.3
unnamed: J5.4, J6.4
unnamed: J5.5, J6.5
unnamed: J5.6, J6.6
unnamed: J5.7, J6.7
unnamed: J5.8, J6.8
unnamed: J5.9, J6.9
unnamed: J5.10, J6.10
unnamed: J7.1, J8.1
unnamed: J7.2, J8.2
unnamed: J7.3, J8.3
unnamed: J7.4, J8.4
unnamed: J7.5, J8.5
unnamed: J7.6, J8.6
unnamed: J7.7, J8.7
unnamed: J7.8, J8.8
unnamed: J7.9, J8.9
unnamed: J7.10, J8.10
unnamed: J9.R, R13.1
unnamed: J9.T, R12.1
unnamed: J12.1, J13.R
unnamed: J12.2, J13.RN
unnamed: J12.3, J13.S
unnamed: J12.4, J13.TN
unnamed: J12.5, J13.T
unnamed: J14.1, J15.R
unnamed: J14.2, J15.RN
unnamed: J14.3, J15.S
unnamed: J14.4, J15.TN
unnamed: J14.5, J15.T
unnamed: R8.2, U1.7
unnamed: R9.2, SW8.2, U1.6
VCC: A1.27, C1.1, C3.1, D8.1, J3.12, J10.12, R1.2, R9.1, R11.2, RV1.1, RV2.1, RV3.1, RV4.1, U1.8

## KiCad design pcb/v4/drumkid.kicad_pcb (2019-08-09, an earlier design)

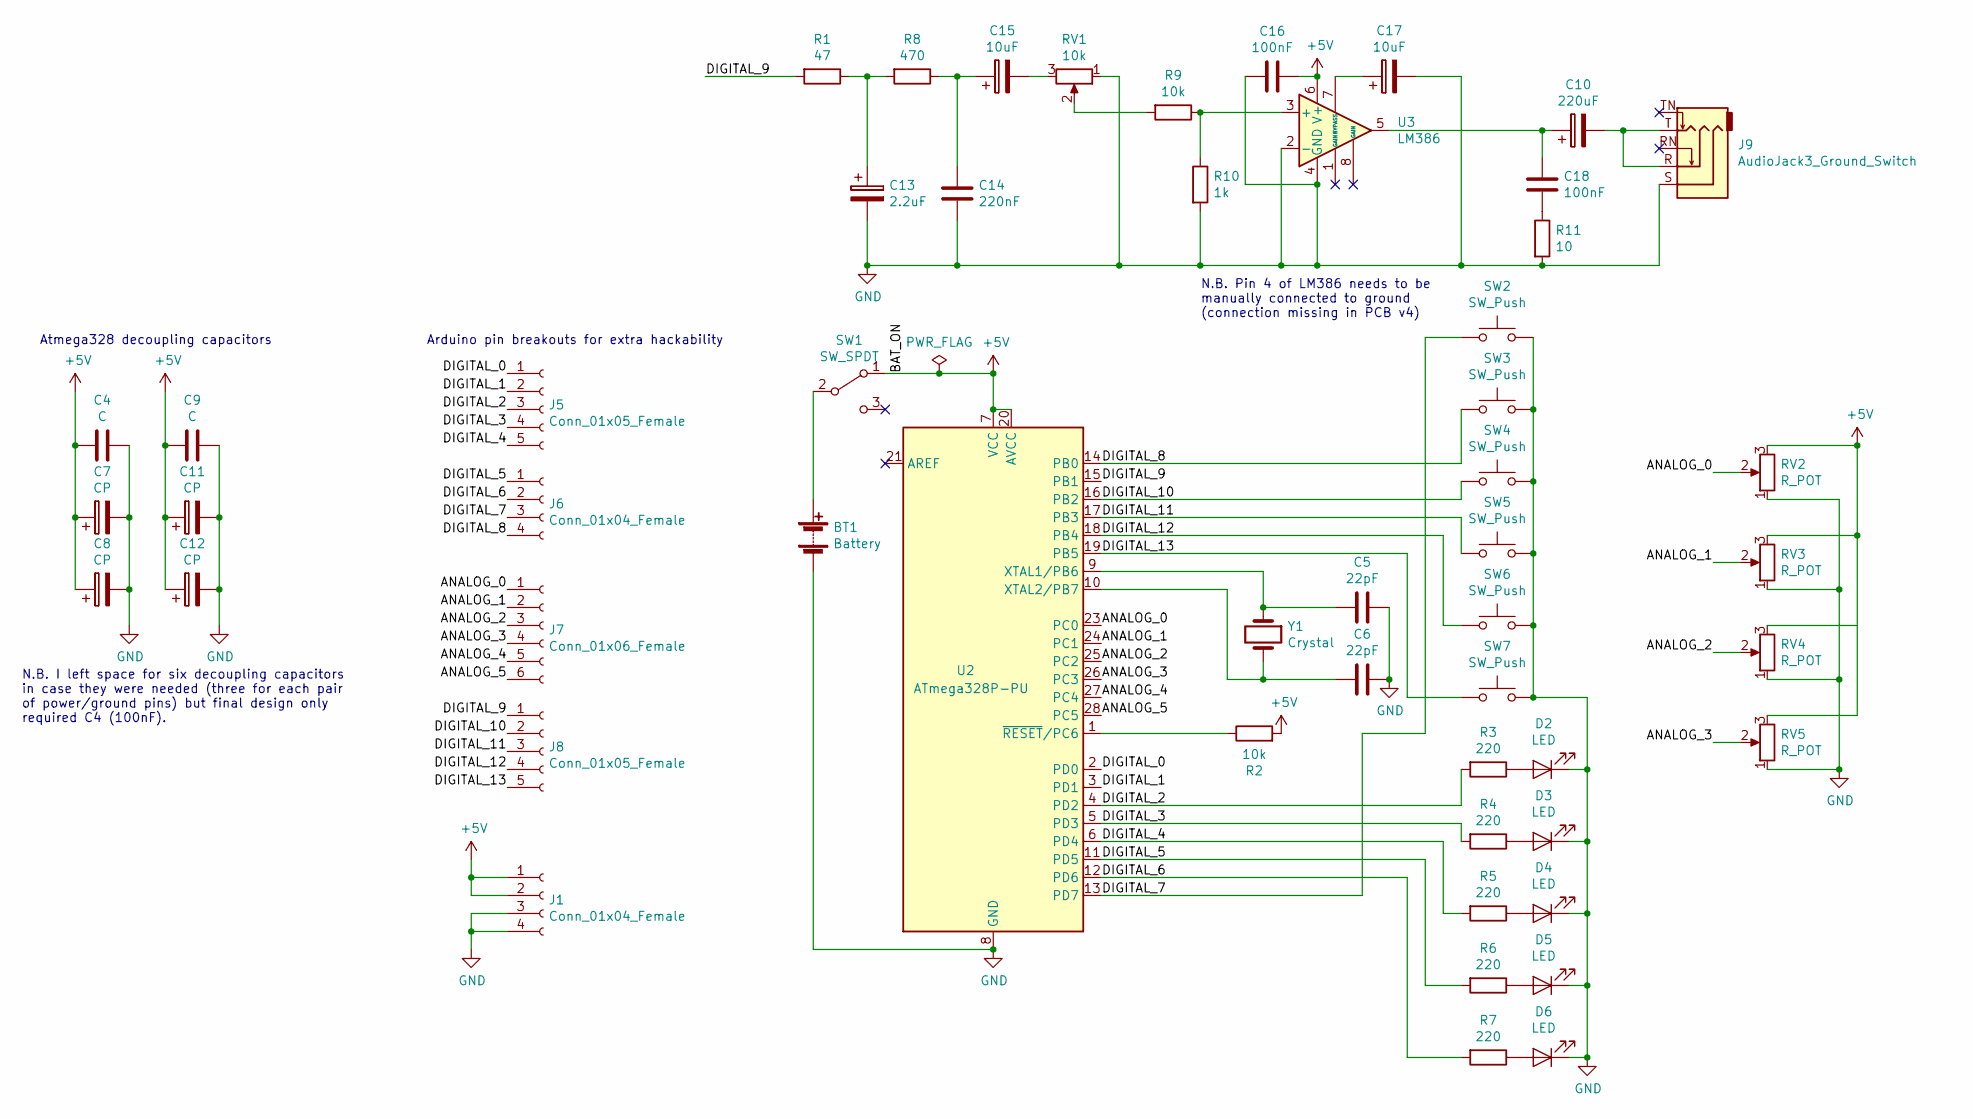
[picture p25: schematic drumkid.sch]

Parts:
BT1: Battery; PinHeader_1x02_P2.54mm_Vertical
C4, C9: C; C_Disc_D3.4mm_W2.1mm_P2.50mm
C5, C6: 22pF; C_Disc_D3.4mm_W2.1mm_P2.50mm
C7, C8, C11, C12: CP; CP_Radial_D6.3mm_P2.50mm
C10: 220uF; CP_Radial_D6.3mm_P2.50mm
C13: 2.2uF; CP_Radial_D6.3mm_P2.50mm
C14: 220nF; C_Disc_D3.4mm_W2.1mm_P2.50mm
C15, C17: 10uF; CP_Radial_D6.3mm_P2.50mm
C16, C18: 100nF; C_Disc_D3.4mm_W2.1mm_P2.50mm
D2, D3, D4, D5, D6: LED; LED_D5.0mm
J1, J6: Conn_01x04_Female; PinHeader_1x04_P2.54mm_Vertical
J5, J8: Conn_01x05_Female; PinHeader_1x05_P2.54mm_Vertical
J7: Conn_01x06_Female; PinHeader_1x06_P2.54mm_Vertical
J9: AudioJack3_Ground_Switch; Tayda_3.5mm_stereo_TRS_jack_A-853
R1: 47; R_Axial_DIN0207_L6.3mm_D2.5mm_P10.16mm_Horizontal
R2, R9: 10k; R_Axial_DIN0207_L6.3mm_D2.5mm_P10.16mm_Horizontal
R3, R4, R5, R6, R7: 220; R_Axial_DIN0207_L6.3mm_D2.5mm_P10.16mm_Horizontal
R8: 470; R_Axial_DIN0207_L6.3mm_D2.5mm_P10.16mm_Horizontal
R10: 1k; R_Axial_DIN0207_L6.3mm_D2.5mm_P10.16mm_Horizontal
R11: 10; R_Axial_DIN0207_L6.3mm_D2.5mm_P10.16mm_Horizontal
RV1: 10k; Potentiometer_Alps_RK09K_Single_Vertical
RV2, RV3, RV4, RV5: R_POT; Potentiometer_Alps_RK09K_Single_Vertical
SW1: SW_SPDT; EG1206
SW2, SW3, SW4, SW5, SW6, SW7: SW_Push; SW_PUSH-12mm_Wuerth-430476085716
U2: ATmega328P-PU; DIP-28_W7.62mm_Socket
U3: LM386; DIP-8_W7.62mm_Socket
Y1: Crystal; Crystal_HC49-4H_Vertical

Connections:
+5V: C4.2, C7.1, C8.1, C9.2, C11.1, C12.1, C16.1, J1.1, J1.2, R2.2, RV2.3, RV3.3, RV4.3, RV5.3, SW1.1 (A), U2.7 (VCC), U2.20 (AVCC), U3.6 (V+)
/ANALOG_0: J7.1, RV2.2, U2.23 (PC0)
/ANALOG_1: J7.2, RV3.2, U2.24 (PC1)
/ANALOG_2: J7.3, RV4.2, U2.25 (PC2)
/ANALOG_3: J7.4, RV5.2, U2.26 (PC3)
/ANALOG_4: J7.5, U2.27 (PC4)
/ANALOG_5: J7.6, U2.28 (PC5)
/DIGITAL_0: J5.1, U2.2 (PD0)
/DIGITAL_1: J5.2, U2.3 (PD1)
/DIGITAL_2: J5.3, R3.2, U2.4 (PD2)
/DIGITAL_3: J5.4, R4.2, U2.5 (PD3)
/DIGITAL_4: J5.5, R5.2, U2.6 (PD4)
/DIGITAL_5: J6.1, R6.2, U2.11 (PD5)
/DIGITAL_6: J6.2, R7.2, U2.12 (PD6)
/DIGITAL_7: J6.3, SW2.1, U2.13 (PD7)
/DIGITAL_8: J6.4, SW3.1, U2.14 (PB0)
/DIGITAL_9: J8.1, R1.2, U2.15 (PB1)
/DIGITAL_10: J8.2, SW4.1, U2.16 (PB2)
/DIGITAL_11: J8.3, SW5.1, U2.17 (PB3)
/DIGITAL_12: J8.4, SW6.1, U2.18 (PB4)
/DIGITAL_13: J8.5, SW7.1, U2.19 (PB5)
unnamed: BT1.1 (+), SW1.2 (B)
unnamed: C5.1, U2.9 (XTAL1/PB6), Y1.1
unnamed: C6.1, U2.10 (XTAL2/PB7), Y1.2
unnamed: C10.1, C18.1, U3.5
unnamed: C10.2, J9.R, J9.T
unnamed: C13.1, R1.1, R8.2
unnamed: C14.1, C15.1, R8.1
unnamed: C15.2, RV1.3
unnamed: C17.1, U3.7 (BYPASS)
unnamed: C18.2, R11.1
unnamed: D2.2 (A), R3.1
unnamed: D3.2 (A), R4.1
unnamed: D4.2 (A), R5.1
unnamed: D5.2 (A), R6.1
unnamed: D6.2 (A), R7.1
unnamed: R2.1, U2.1 (~RESET~/PC6)
unnamed: R9.2, RV1.2
unnamed: R9.1, R10.1, U3.3 (+)

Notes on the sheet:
Atmega328 decoupling capacitors
Arduino pin breakouts for extra hackability
N.B. Pin 4 of LM386 needs to be manually connected to ground (connection missing in PCB v4)
N.B. I left space for six decoupling capacitors in case they were needed (three for each pair of power/ground pins) but final design only required C4 (100nF).

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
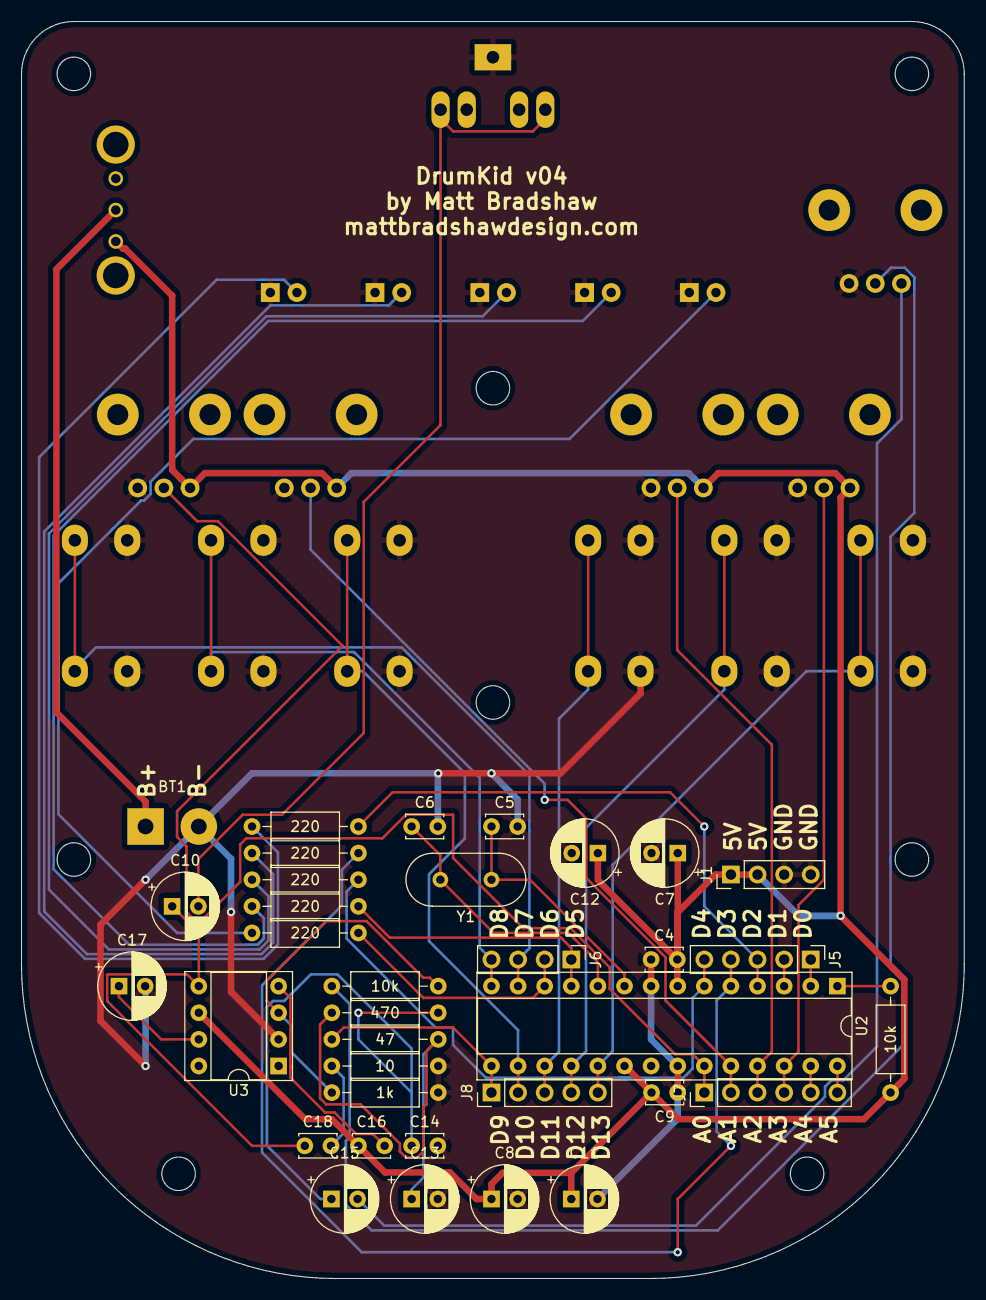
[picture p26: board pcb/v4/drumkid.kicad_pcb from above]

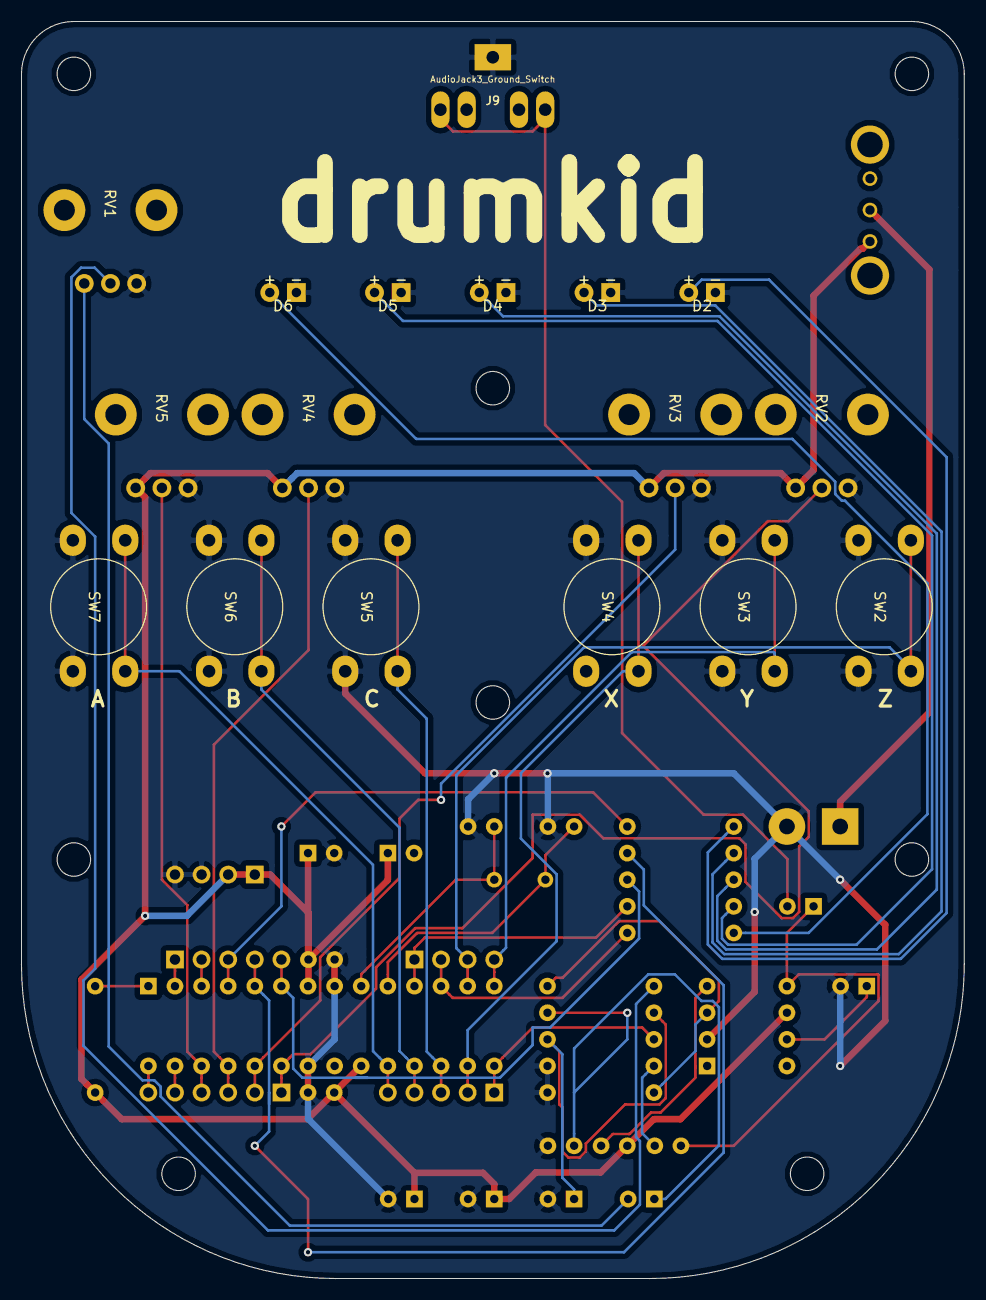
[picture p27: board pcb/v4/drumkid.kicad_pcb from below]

Board: 2 copper layers, 90.0 x 120.0 mm, 53 parts (18 on the bottom side), 41 nets.

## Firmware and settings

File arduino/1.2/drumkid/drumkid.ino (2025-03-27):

/*  DrumKid firmware V1.2
 *  This code should work for DrumKid boards from V6 onwards.
 *  It might work with earlier versions with a bit of tweaking :) 
 */

// include debouncing library to make buttons work reliably
#include "src/Bounce2/src/Bounce2.h"

// include Mozzi library files for generating audio (custom version to allow reverse playback)
#include "src/MozziDK/src/MozziGuts.h"
#include "src/MozziDK/src/Sample.h"
#include "src/MozziDK/src/mozzi_rand.h"
#include "src/MozziDK/src/Oscil.h"
#include "src/MozziDK/src/tables/saw256_int8.h"

// include drum beat pattern definitions from separate file
#include "beats.h"

// include sample data (generated via Python script)
#include "sample0.h"
#include "sample1.h"
#include "sample2.h"
#include "sample3.h"
#include "sample4.h"

// declare samples as Mozzi sample objects
Sample <sample0_NUM_CELLS, AUDIO_RATE> sample0(sample0_DATA);
Sample <sample1_NUM_CELLS, AUDIO_RATE> sample1(sample1_DATA);
Sample <sample2_NUM_CELLS, AUDIO_RATE> sample2(sample2_DATA);
Sample <sample3_NUM_CELLS, AUDIO_RATE> sample3(sample3_DATA);
Sample <sample4_NUM_CELLS, AUDIO_RATE> sample4(sample4_DATA);

// define oscillators for drone
Oscil<SAW256_NUM_CELLS, AUDIO_RATE> droneOscillator1(SAW256_DATA);
Oscil<SAW256_NUM_CELLS, AUDIO_RATE> droneOscillator2(SAW256_DATA);

// include EEPROM library for saving data
#include <EEPROM.h>

// declare buttons as Bounce objects
Bounce buttons[6];

// Mozzi control rate, measured in Hz, must be power of 2
// try to keep this value as high as possible (256 is good) but reduce if having performance issues
#define CONTROL_RATE 128

// define various values
#define NUM_KNOBS 4
#define NUM_LEDS 5
#define NUM_BUTTONS 6
#define NUM_SAMPLES 5
#define NUM_PARAM_GROUPS 4
#define SAVED_STATE_SLOT_BYTES 24
#define NUM_TAP_TIMES 8
#define MAX_BEATS_PER_BAR 13

// define pin numbers
// keep pin 9 for audio, but others can be changed to suit your breadboard layout
const byte ledPins[5] = {2,3,11,12,13};
const byte buttonPins[6] = {4,5,6,7,8,10};
const byte analogPins[4] = {A0,A1,A2,A3};

// various other global variables
float nextPulseTime = 0.0; // the time, in milliseconds, of the next pulse
float msPerPulse = 20.8333; // time for one "pulse" (there are 24 pulses per quarter note, as defined in MIDI spec)
byte pulseNum = 0; // 0 to 23 (24ppqn, pulses per quarter note)
unsigned int stepNum = 0; // 0 to 192 (max two bars of 8 beats, aka 192 pulses)
unsigned int numSteps; // number of steps used - dependent on time signature
unsigned int specialOffset = 0; // number of steps to offset pattern in random time signature mode
bool beatPlaying = false; // true when beat is playing, false when not
byte noteDown = B00000000; // keeps track of whether a MIDI note is currently down or up
bool syncReceived = false; // has a sync/clock signal been received? (IMPROVE THIS LATER)
byte midiNotes[NUM_SAMPLES]; // MIDI note numbers
const byte defaultMidiNotes[NUM_SAMPLES] = {36,42,38,37,43}; // default MIDI note numbers
byte midiNoteCommands[NUM_SAMPLES]; // MIDI note on commands
byte sampleVolumes[NUM_SAMPLES] = {0,0,0,0,0}; // current sample volumes
byte storedValues[NUM_PARAM_GROUPS*NUM_KNOBS]; // analog knob values, one for each parameter (so the value can be remembered even after switching groups)
byte firstLoop = true; // allows special actions on first loop
byte secondLoop = false; // allows special actions on second loop
bool newMidiDroneRoot = false;
byte controlSet = 0; // current active set of parameters
byte knobLocked = B11111111; // record whether a knob's value is currently "locked" (i.e. won't alter effect until moved by a threshold amount)
byte analogValues[NUM_KNOBS]; // current analog (knob) values
byte initValues[NUM_KNOBS]; // initial parameter values
byte specialLedDisplayNum; // binary number to display on LEDs (when needed)
unsigned long specialLedDisplayTime = 0; // the last time the LEDs were told to display a number

// save/load variables
bool readyToChooseSaveSlot = false;
bool readyToChooseLoadSlot = false;
bool readyToChooseBank = false;
bool newStateLoaded = false;
byte activeBank = 0;
byte activeMidiSettingsNum = 0;

// tempo variables
float tapTimes[NUM_TAP_TIMES];
byte nextTapIndex = 0;

// parameter variables, each with a range of 0-255 unless otherwise noted
byte paramChance;
byte paramZoom;
int paramMidpoint; // -255 to 255
int paramRange; // 0 to 510
byte paramPitch;
byte paramCrush;
byte paramCrop;
byte paramDrop;
byte paramBeat; // 0 to 23 (24 beats in total)
byte paramTimeSignature; // 1 to 13 (3/4, 4/4, 5/4, 6/4, 7/4)
float paramTempo; 
byte paramSwing = 0; // 0 to 2 (0=straight, 1=approx quintuplet swing, 2=triplet swing)
byte paramDroneRoot; // 0 to 11 (all 12 possible semitones in an octave)
float paramDronePitch;
byte paramDroneMod;

// special global variables needed for certain parameters
byte crushCompensation;
byte previousBeat;
byte previousDroneRoot;
byte activeDroneRoot;
byte previousTimeSignature;
byte oscilGain1 = 255;
byte oscilGain2 = 255;
bool droneMod2Active = false;
#define MIN_TEMPO 40
#define MAX_TEMPO 295

#if MIN_TEMPO + 255 != MAX_TEMPO
#error "Tempo must have a range of exactly 255 otherwise I'll have to write more code"
#endif

// define which knob controls which parameter
// e.g. 0 is group 1 knob 1, 6 is group 2 knob 3
#define CHANCE 0
#define ZOOM 1
#define RANGE 2
#define MIDPOINT 3

#define PITCH 4
#define CRUSH 5
#define CROP 6
#define DROP 7

#define DRONE 8
#define DRONE_MOD 9
#define DRONE_PITCH 10
#define DRONE_ROOT 11

#define BEAT 12
#define TIME_SIGNATURE 13
#define SWING 14
#define TEMPO 15

// define root notes
float rootNotes[13] = {
  138.5913155f,
  146.832384f,
  155.5634919f,
  164.8137785f,
  174.6141157f,
  184.9972114f,
  195.997718f,
  207.6523488f,
  220.0f,
  233.0818808f,
  246.9416506f,
  261.6255653f,
  277.182631f,
};

// determines whether each sample is played or muted in a particular drop mode
byte dropRef[NUM_SAMPLES] = {
  B00011110, // kick
  B11111000, // hat
  B00110000, // snare
  B01111000, // rim
  B00011100, // tom
};

void setup(){
  byte i;

  checkEepromScheme(); // write defaults to memory if not previously done
  initialiseSettings(false);
  
  for(i=0;i<NUM_LEDS;i++) {
    pinMode(ledPins[i],OUTPUT); // set LED pins as outputs
  }

  randSeed((long)analogRead(4)*analogRead(5)); // A4 and A5 should be floating, use to seed random numbers
  startMozzi(CONTROL_RATE);

  // initialise all buttons using Bounce2 library
  for(i=0; i<NUM_BUTTONS; i++) {
    buttons[i].interval(25);
    buttons[i].attach(buttonPins[i], INPUT_PULLUP);
  }

  // set starting values for each parameter
  resetSessionToDefaults();
  
  Serial.begin(31250); // begin serial communication for MIDI input/output
  //Serial.begin(9600);

  flashLeds(); // do a brief LED light show to show the unit is working
}

byte buttonsPressed = 0;
byte buttonGroup = 0;
byte lastButtonsPressed = 0;
byte menuState = 0;

void updateControl(){
  byte i;
  bool controlSetChanged = false;
  newStateLoaded = false;
  byte prevControlSet = controlSet;
  
  for(i=0; i<6; i++) {
    buttons[i].update();
  }
  for(i=0; i<6; i++) {
    bitWrite(buttonsPressed,i,!buttons[i].read());
    buttonGroup = buttonsPressed | buttonGroup;
  }
  if(buttonsPressed != lastButtonsPressed) {
    if(menuState == 0) {
      if(buttons[0].fell()) {
        if(!beatPlaying) startBeat();
        else stopBeat();
      }
      if(buttons[5].fell()) {
        tapTimes[nextTapIndex] = (float) millis();

        float firstTime;
        float timeTally = 0.0;
        byte validTimes = 0;
        bool keepChecking = true;
        for(i=0;i<NUM_TAP_TIMES-1 && keepChecking;i++) {
          byte thisTapIndex = (nextTapIndex + NUM_TAP_TIMES - i) % NUM_TAP_TIMES;
          byte lastTapIndex = (nextTapIndex + NUM_TAP_TIMES - i - 1) % NUM_TAP_TIMES;
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
void loop(){
  while(Serial.available()) {
    thisMidiByte = Serial.read();
    if(bitRead(thisMidiByte,7)) {
      // status byte
      midiBytes[0] = thisMidiByte;
      if(thisMidiByte==0xFA) {
        // clock start signal received
        startBeat();
      } else if(thisMidiByte==0xFB) {
        // clock continue signal received
        startBeat();
      } else if(thisMidiByte==0xFC) {
        // clock stop signal received
        stopBeat();
      } else if(thisMidiByte==0xF8) {
        // clock signal received
        syncReceived = true;
        if(beatPlaying) {
          doPulseActions();
        }
      }
      currentMidiByte = 1;
    } else {
      // data byte
      midiBytes[currentMidiByte] = thisMidiByte;
      if((midiBytes[0]>>4)==0xB && currentMidiByte == 2) {
        // CC message (any channel)
        if(midiBytes[1]>=16&&midiBytes[1]<32) {
          byte paramNum = midiBytes[1] - 16;
          byte paramSet = paramNum / 4;
          byte paramSetNum = paramNum % 4;
          storedValues[paramNum] = midiBytes[2] * 2;
          if(controlSet==paramSet) {
            bitWrite(knobLocked, paramSetNum, true);
            initValues[paramSetNum] = analogValues[paramSetNum];
          }
          updateParameters(paramSet);
        }
      } else if((midiBytes[0]>>4)==0x9 && currentMidiByte == 2) {
        // Note on (any channel)
        if(midiBytes[2] > 0) {
          newMidiDroneRoot = true;
          byte paramSet = DRONE_ROOT / 4;
          byte paramSetNum = DRONE_ROOT % 4;
          storedValues[DRONE_ROOT] = (midiBytes[1] % 12) * 20;
          if(controlSet==paramSet) {
            bitWrite(knobLocked, paramSetNum, true);
            initValues[paramSetNum] = analogValues[paramSetNum];
          }
          updateParameters(paramSet);
          newMidiDroneRoot = false;
        }
      } else if((midiBytes[0]>>4==0xC) && currentMidiByte == 1) {
        // program change (beat number)
        if(midiBytes[1]<NUM_BEATS) {
          paramBeat = midiBytes[1];
        } else {
          paramBeat = NUM_BEATS - 1;
        }
        previousBeat = paramBeat;
      }
      // MIDI thru, experimental, only certain message types
      bool useMidiThru = false;
      if(useMidiThru) {
        if(currentMidiByte == 2) {
          switch(midiBytes[0]>>4) {
            case 0xB:
            // CC
            case 0x9:
            // note on
            case 0xC:
            // program change
            case 0x8:
            // note off
            Serial.write(midiBytes[0]);           
            Serial.write(midiBytes[1]);
            Serial.write(midiBytes[2]);
            break;
          }
        }
      }
      currentMidiByte ++;
    }
  }
  audioHook(); // main Mozzi function, calls updateAudio and updateControl
}

void flashLeds() {
  byte i, randByte;
  for(i=0;i<30;i++) {
    randByte = rand(0,256);
    displayLedNum(randByte);
    while(millis()<(i+1)*25) {
      // do nothing here
      // this is a silly hack so that the delay() function doesn't get compiled
      // this is what happens when your program takes up 99%+ of the storage space
    }
  }
  displayLedNum(0);
}

void updateLeds() {
  if(millis() < specialLedDisplayTime + 750UL && specialLedDisplayTime > 0) {
    // show desired binary number for certain parameters where visual feedback is helpful
    displayLedNum(specialLedDisplayNum);
  } else if(beatPlaying && menuState == 0) {
    //if(stepNum==0||(paramTimeSignature==4&&stepNum==96)||(paramTimeSignature==6&&stepNum==72)) displayLedNum(B00000011);
    if(stepNum==0) displayLedNum(B00000011);
    else if(stepNum%24==0) displayLedNum(B00000010);
    else if(stepNum%24==3) displayLedNum(B00000000);
  } else {
    displayLedNum(B00000000);
  }
}

void displayLedNum(byte displayNum) {
  byte i;
  for(i=0;i<NUM_LEDS;i++) {
    digitalWrite(ledPins[i], bitRead(displayNum,i));
  }
}

void specialLedDisplay(byte displayNum, bool isBinary) {
  if(!firstLoop&&!secondLoop) {
    if(isBinary) {
      specialLedDisplayNum = displayNum;
    } else {
      specialLedDisplayNum = B00000000;
      bitWrite(specialLedDisplayNum,displayNum%NUM_LEDS,HIGH);
    }
    specialLedDisplayTime = millis();
  }
}

float byteToTempo(byte tempoByte) {
  float tempoFloat;
  if(tempoByte<=192) {
    tempoFloat = 10.0 + tempoByte;
  } else {
    tempoFloat = 202.0 + 12.66667 * (tempoByte - 192.0);
  }
  return tempoFloat;
}

byte tempoToByte(float tempoFloat) {
  byte tempoByte;
  if(tempoFloat<=202.0) {
    tempoByte = ((byte) tempoFloat) - 10;
  } else {
    tempoByte = (byte) ((tempoFloat - 202.0) / 12.66667) + 192;
  }
  return tempoByte;
}

void chooseBank(byte newBank) {
  activeBank = newBank;
  readyToChooseBank = false;
}

void resetSessionToDefaults() {
  // set starting values for each parameter
  storedValues[CHANCE] = 128;
  storedValues[ZOOM] = 150;
  storedValues[RANGE] = 0;
  storedValues[MIDPOINT] = 128;
  
  storedValues[PITCH] = 160;
  storedValues[CRUSH] = 255;
  storedValues[CROP] = 255;
  storedValues[DROP] = 128;

  storedValues[DRONE_MOD] = 127;
  storedValues[DRONE] = 127;
  storedValues[DRONE_ROOT] = 0;
  storedValues[DRONE_PITCH] = 127;

  storedValues[BEAT] = 27;
  storedValues[TIME_SIGNATURE] = 64; // equates to 4/4
  storedValues[SWING] = 0;
  storedValues[TEMPO] = 110; // actually equates to 120BPM

  newStateLoaded = true;
  for(byte i=0;i<NUM_PARAM_GROUPS;i++) {
    updateParameters(i); // set parameters to initial values defined above
  }
}

void createRandomSession() {
  storedValues[CHANCE] = rand(64,192);
  storedValues[ZOOM] = rand(100,190);
  storedValues[RANGE] = rand(0,128);
  storedValues[MIDPOINT] = rand(80,190);
  
  storedValues[PITCH] = rand(135,256);
  if(rand(0,6)==0) storedValues[PITCH] = rand(0,120);
  storedValues[CRUSH] = rand(160,256);
  storedValues[CROP] = rand(128,256);
  storedValues[DROP] = 128;
  if(rand(0,3)==0) storedValues[DROP] = rand(29,226);

  storedValues[DRONE_MOD] = 127;
  storedValues[DRONE] = 127;
  storedValues[DRONE_ROOT] = rand(0,256);
  storedValues[DRONE_PITCH] = 127;
  if(rand(0,6)==0) storedValues[DRONE_MOD] = rand(0,256);
  if(rand(0,4)==0) storedValues[DRONE] = rand(64,192);

  storedValues[BEAT] = rand(0,240);

  if(!beatPlaying) {
    // don't randomise time signature and tempo unless stopped
    storedValues[TIME_SIGNATURE] = 64; // equates to 4/4
    if(rand(0,3)==0) storedValues[TIME_SIGNATURE] = rand(0,256);
    storedValues[TEMPO] = rand(70,160);
    if(rand(0,4)==0) storedValues[TEMPO] = rand(0,256);
  }
  storedValues[SWING] = rand(0,256);

  newStateLoaded = true;
  for(byte i=0;i<NUM_PARAM_GROUPS;i++) {
    updateParameters(i); // set parameters to initial values defined above
  }
}

void loadParams(byte slotNum) {
  readyToChooseLoadSlot = false;
  newStateLoaded = true;
  for(byte i=0; i<NUM_PARAM_GROUPS*NUM_KNOBS; i++) {
    if(!(i==TEMPO&&beatPlaying)) {
      byte thisValue = EEPROM.read((slotNum+6*activeBank)*SAVED_STATE_SLOT_BYTES+i);
      storedValues[i] = thisValue;
    }
  }
  for(byte i=0;i<NUM_PARAM_GROUPS;i++) {
    updateParameters(i);
  }
}

void saveParams(byte slotNum) {
  // 1024 possible byte locations in EEPROM
  // currently need 16 bytes per saved state (4 groups of 4 params, 1 byte per param)
  // 36 possible save slots (6 banks of 6 slots)
  // need to leave space for some possible extra saved state data in future
  // allot 24 bytes per saved state (vaguely round number in binary), taking up total of 864 bytes
  readyToChooseSaveSlot = false;
  for(byte i=0; i<NUM_PARAM_GROUPS*NUM_KNOBS; i++) {
    EEPROM.write((slotNum+6*activeBank)*SAVED_STATE_SLOT_BYTES+i, storedValues[i]);
  }
}

// prior to firmware version 1.1, no way of knowing whether older firmware was previously installed
// from V1.1 onwards, new special address beyond the 864 bytes reserved for storing sessions
// Slot 864-865: if these bytes have values 119 and 206 respectively, we are using the new memory system (1 in 65,025 chance of these being randomly correct)
// Slot 866: current version (0 = V1.1, 1 = V1.2)
// Slots 867-871: reserved for other version stuff if needed
// Slots 872-879: MIDI note numbers for channels 1 through 5 (and another 3 reserved)
// Slots 880-887: MIDI channel numbers for channels 1 through 5 (and another 3 reserved)
// Slots 888+: free for future features
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

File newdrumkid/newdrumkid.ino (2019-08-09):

#define IS_BREADBOARD false // switch to false if compiling code for PCB

// include mozzi library files
#include <MozziGuts.h>
#include <Sample.h>
#include <EventDelay.h>
#include <mozzi_rand.h>

// include debouncing library
#include <Bounce2.h>

// include audio data files
#include "kick.h"
#include "closedhat.h"
#include "snare.h"
#include "click.h"

// define buttons
Bounce buttonA = Bounce();
Bounce buttonB = Bounce();
Bounce buttonC = Bounce();
Bounce buttonX = Bounce();
Bounce buttonY = Bounce();
Bounce buttonZ = Bounce();

#define CONTROL_RATE 256 // tweak this value if performance is bad, must be power of 2 (64, 128, etc)
#define MAX_BEAT_STEPS 32

bool sequencePlaying = false; // false when stopped, true when playing
byte currentStep;
byte numSteps = 4 * 16; // 64 steps = 4/4 time signature, 48 = 3/4 or 6/8, 80 = 5/4, 112 = 7/8 etc
float nextNoteTime;
float scheduleAheadTime = 100; // ms
float lookahead = 25; // ms
const byte numEventDelays = 20;
EventDelay schedulerEventDelay;
EventDelay eventDelays[numEventDelays];
bool delayInUse[numEventDelays];
byte delayChannel[numEventDelays];
byte delayVelocity[numEventDelays];
byte eventDelayIndex = 0;
bool beatLedsActive = true;
bool firstLoop = true;
byte sampleVolumes[4] = {255,255,255,255};

// variables relating to knob values
byte controlSet = 0;
bool knobLocked[4] = {true,true,true,true};
int analogValues[4] = {0,0,0,0};
int initValues[4] = {0,0,0,0};
int storedValues[5][4] = {  {512,512,512,512},    // A
                            {512,512,512,512},    // B
                            {512,512,512,512},    // C
                            {512,512,512,512},    // X
                            {512,512,512,512},};  // Y

// parameters
byte paramChance = 0;
byte paramMidpoint = 0;
byte paramRange = 0;
byte paramZoom = 0;
byte paramPitch = 0;
byte paramCrush = 0;
byte crushCompensation = 0;
int paramSlop = 0;
float paramTempo = 120.0;
byte paramTimeSignature = 4;

// define samples
Sample <kick_NUM_CELLS, AUDIO_RATE> kick1(kick_DATA);
Sample <closedhat_NUM_CELLS, AUDIO_RATE> closedhat1(closedhat_DATA);
Sample <snare_NUM_CELLS, AUDIO_RATE> snare1(snare_DATA);
Sample <click_NUM_CELLS, AUDIO_RATE> click1(click_DATA);

byte beat1[][MAX_BEAT_STEPS] = {  {255,255,0,0,0,0,0,0,255,0,0,0,0,0,0,0,255,255,0,0,0,0,0,0,255,0,0,0,0,0,0,0,},
                                  {255,128,255,128,255,128,255,128,255,128,255,128,255,128,255,128,255,128,255,128,255,128,255,128,255,128,255,128,255,128,255,128,},
                                  {0,0,0,0,255,0,0,0,0,0,0,0,255,128,64,32,0,0,0,0,255,0,0,0,0,0,0,0,255,128,64,32,},
                                  {0,128,0,128,0,128,0,128,0,128,0,128,0,128,0,128,0,128,0,128,0,128,0,128,0,128,0,128,0,128,0,128,},};

// define pins
byte breadboardLedPins[5] = {2,3,4,5,13};
byte breadboardButtonPins[6] = {7,8,10,11,12,6};
byte pcbLedPins[5] = {6,5,4,3,2};
byte pcbButtonPins[6] = {13,12,11,10,8,7};
byte (&ledPins)[5] = IS_BREADBOARD ? breadboardLedPins : pcbLedPins;
byte (&buttonPins)[6] = IS_BREADBOARD ? breadboardButtonPins : pcbButtonPins;

void setup() {
  startMozzi(CONTROL_RATE);
  randSeed();
  kick1.setFreq((float) kick_SAMPLERATE / (float) kick_NUM_CELLS);
  closedhat1.setFreq((float) closedhat_SAMPLERATE / (float) closedhat_NUM_CELLS);
  snare1.setFreq((float) snare_SAMPLERATE / (float) snare_NUM_CELLS);
  click1.setFreq((float) click_SAMPLERATE / (float) click_NUM_CELLS);
  kick1.setEnd(7000);
  Serial.begin(9600);
  for(byte i=0;i<5;i++) {
    pinMode(ledPins[i], OUTPUT);
  }

  buttonA.interval(25);
  buttonB.interval(25);
  buttonC.interval(25);
  buttonX.interval(25);
  buttonY.interval(25);
  buttonZ.interval(25);
  buttonA.attach(buttonPins[0], INPUT_PULLUP);
  buttonB.attach(buttonPins[1], INPUT_PULLUP);
  buttonC.attach(buttonPins[2], INPUT_PULLUP);
  buttonX.attach(buttonPins[3], INPUT_PULLUP);
  buttonY.attach(buttonPins[4], INPUT_PULLUP);
  buttonZ.attach(buttonPins[5], INPUT_PULLUP);

  for(int i=0;i<20000;i++) {
    kick1.next();
    closedhat1.next();
    snare1.next();
  }
  startupLedSequence();
}

void loop() {
  audioHook();
}

void nextNote() {
  float msPerBeat = (60.0 / paramTempo) * 1000.0;
  nextNoteTime += 0.25 * msPerBeat / 4;
  currentStep ++;
  currentStep = currentStep % numSteps;
}

void scheduleNote(byte channelNumber, byte beatNumber, byte velocity, float delayTime) {
  // schedule a drum hit to occur after [delayTime] milliseconds
  eventDelays[eventDelayIndex].set(delayTime);
  eventDelays[eventDelayIndex].start();
  delayInUse[eventDelayIndex] = true;
  delayChannel[eventDelayIndex] = channelNumber;
  delayVelocity[eventDelayIndex] = velocity;
  eventDelayIndex = (eventDelayIndex + 1) % numEventDelays; // replace with "find next free slot" function
}

void scheduler() {
  while(nextNoteTime < (float) millis() + scheduleAheadTime) {
    byte thisStep = currentStep/16;
    byte stepLED = constrain(thisStep, 0, 4);
    if(beatLedsActive) {
      if(currentStep%16==0) digitalWrite(ledPins[stepLED], HIGH);
      else if(currentStep%4==0) digitalWrite(ledPins[stepLED], LOW);
    }
    for(byte i=0;i<4;i++) {
      int slopRand = rand(0,paramSlop) - paramSlop / 2;
      if(currentStep%4==0&&beat1[i][currentStep/4]>0) scheduleNote(i, currentStep, beat1[i][currentStep/4], nextNoteTime + slopRand - (float) millis());
      else {
        // temp, playing around
        if(currentStep%4==0) {
          byte yesNoRand = rand(0,255);
          if(yesNoRand < paramChance) {
            long velocityRand = rand(0,255); // is long necessary?
            long velocity = paramMidpoint - paramRange/2 + ((velocityRand * paramRange)>>8); // is long necessary?
            if(velocity > 0) scheduleNote(i, currentStep, velocity, nextNoteTime - (float) millis());
          }
        }
      }
    }
    nextNote();
  }
  schedulerEventDelay.set(lookahead);
  schedulerEventDelay.start();
}

void play() {
  sequencePlaying = !sequencePlaying;

  if(sequencePlaying) {
    // start
    currentStep = 0;
    nextNoteTime = millis();
    scheduler();
  } else {
    // stop
    for(byte i=0; i<5; i++) {
      digitalWrite(ledPins[i], LOW);
    }
    // cancel "timeout" somehow..?
  }
}
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

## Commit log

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2019-02-20 pitch shift working - sounds glitchy and cool
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2019-03-20 omg the circuit works!
    [drumkid.sch]
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2019-03-21 assigned a bunch of footprints but missing some
    [drumkid.sch]
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2019-03-21 pcb layout looking nice-ish
    [drumkid.kicad_pcb]
2019-03-21 quick commit before i finalise the layout
    [drumkid.kicad_pcb]
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2019-03-22 layout finalised, gerbers generated, boards in production!
    [drumkid-B.Cu.gbr, drumkid-B.Mask.gbr, drumkid-B.SilkS.gbr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]
2019-04-11 changed pin numbers in code, added LED test at startup, started designing case
    [drumkid_case_1.FCStd]
2019-04-18 lots of work on the 3D case design, and reworked the code to use different pins
    [drumkid.sch, drumkid_button.stl, drumkid_case_1.FCStd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]
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2019-05-08 more pcb changes, about to do a big-ish change so doing a commit now
    [drumkid v2.kicad_pcb, drumkid v2.sch]
2019-05-08 good pcb progress, about to make a little change
    [_saved_drumkid v2.sch, drumkid v2.kicad_pcb, drumkid v2.sch]
2019-05-08 layout done? ready to route tracks
    [_saved_drumkid v2.sch, drumkid v2.kicad_pcb, drumkid v2.sch]
2019-05-08 routing half done maybe
    [drumkid v2.kicad_pcb, drumkid v2.sch]
2019-05-09 routing nearly done but turns out potentiometer footprint is wrong
    [drumkid v2.kicad_pcb]
2019-05-09 2nd pcb done and sent
    [drumkid v2-B.Cu.gbr, drumkid v2-B.Mask.gbr, drumkid v2-B.Paste.gbr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]
2019-05-14 added breadboard fritzing diagram and modified sketch to work on breadboard
    [drumkid breadboard.fzz]
2019-05-24 everything working pretty nicely
    [drumkid v2.sch]
2019-06-25 oops, clearly haven't committed for a while. working on simpler v3 PCB
    [drumkid v3.kicad_pcb, drumkid v3.sch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]
2019-06-25 pcb layout looking nice (v3)
    [drumkid v3.kicad_pcb]
2019-06-25 silkscreen layers looking decent
    [drumkid v3-B.Cu.gbr, drumkid v3-B.Mask.gbr, drumkid v3-B.Paste.gbr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]
2019-06-25 half way through routing
    [drumkid v3.kicad_pcb]
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2019-06-25 routing done! v3 send for fabrication...
    [drumkid v3-B.Cu.gbr, drumkid v3-B.Mask.gbr, drumkid v3-B.Paste.gbr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]
2019-07-10 did a stupid thing and v3 of the PCB is toast - time for v4
    [drumkid v3.csv, drumkid_v3_cover.stl, v3 cover.FCStd]
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2019-07-10 v4 looking good, about to start routing
    [drumkid v3.kicad_pcb]
2019-07-10 v4 in production. i hate routing
    [drumkid v3-B.Cu.gbr, drumkid v3-B.Mask.gbr, drumkid v3-B.Paste.gbr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]
2019-07-31 woah, did a bunch of stuff
    [drumkid cover laser 1.dxf, drumkid cover laser 2.dxf, drumkid laser parts v2.dxf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]
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2019-08-04 added click sound, slop param, tempo param, time signature param
    [newdrumkid.ino]
2019-08-10 big cleanup, deleted old stuff, updated breadboard, changed pins
    [drumkid breadboard.fzz, drumkid_button.stl, drumkid_case_1.FCStd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]
2019-08-10 updated resistor and capacitor values on breadboard
    [drumkid breadboard.fzz]
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2019-08-12 fixed some bugs with save/load
    [drumkid.ino]
2019-08-12 replaced my bad tap tempo function with a nice open source library
    [drumkid.ino]
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2019-08-12 ambitious attempt to add reversed sounds begins here
    [drumkid.ino]
2019-08-12 tried to do reversing by including reversed copies of samples but quickly used up all the memory, abandoning reverse effect for now
    [drumkid.ino]
2019-08-12 omg reversing works! it sounds ace. bit of a hack including a modified copy of mozzi but can sort that out later
    [MozziGuts.cpp, TimerOne.h, drumkid.ino]
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2019-08-14 sorted annoying issue where group A params didn't use defaults
    [drumkid.ino]
2019-08-14 fixed the knob init thing (again) and changed the glitch effect
    [drumkid.ino]
2019-08-14 sorted out tap tempo issues (by including ArduinoTapTempo library and customising it, not sure of best method for stuff like this)
    [drumkid.ino]
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2019-08-18 working on the breadboard schematic
    [drumkid breadboard.fzz]
2019-08-18 breadboard and schematic done
    [drumkid breadboard.fzz]
2019-08-18 breadboard and schematic properly done now
    [drumkid breadboard.fzz]
2019-08-26 cleaned up repo for hackaday prize entry
    [drumkid bom.csv, drumkid cover laser 1.dxf, drumkid cover laser 2.dxf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]
2019-09-17 starting to improve BOM
    [drumkid bom.ods]
2019-09-17 colour coded laser cutting files
    [drumkid laser parts v3.dxf]
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2019-10-19 lots of new stuff - pcb v5 progress, midi code progress, but lots to be done
    [drumkid.kicad_pcb, drumkid.sch]
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2019-10-28 and more pcb stuff
    [drumkid.kicad_pcb, drumkid.sch]
2019-10-29 finished messing about with pcb layout, next comes routing...
    [drumkid.kicad_pcb, drumkid.sch]
2019-10-29 routing done except for gnd
    [drumkid.kicad_pcb]
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2019-11-05 v5 gerbers and MIDI input code
    [drumkid-B.Cu.gbr, drumkid-B.Mask.gbr, drumkid-B.Paste.gbr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]
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2019-11-22 added non-laser-cut (PCB-style) case design after it was requested
    [drumkid.csv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]
2019-11-22 ok, V6 is started, similar to V5 but less broken
    [_saved_drumkid.sch, drumkid.csv, drumkid.kicad_pcb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]
2019-11-24 v6 code coming on nicely, many features implemented
    [_saved_drumkid.sch, drumkid.sch]
2019-11-25 combined swing and slop
    [drumkid.ino]
2019-11-27 nearly all V4 params now working in V6
    [drumkid.kicad_pcb]
2019-11-28 fixed issue where int/byte type confusion was breaking delay function
    [drumkid.ino]
2019-12-02 drift param starting to show some promise
    [drumkid.ino]
2019-12-02 multi-stage drift (aka ghost) almost working
    [drumkid.ino]
2019-12-03 drift function working well
    [drumkid.ino]
2020-01-21 the zoom function is weird and confusing
    [drumkid.kicad_pcb]
2020-01-24 a slightly better glitch effect, now maybe called 'squiggle'
    [drumkid.ino]
2020-01-24 zoom finally working properly and glitch reacts to drift
    [drumkid.ino]
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2020-03-12 new v6 breadboard circuit with arduino nano
    [breadboard.fzz]
2020-03-12 lots of changes to the v6 schematic
    [drumkid.sch]
2020-03-12 new v6 schematic pretty much done
    [drumkid.sch]
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2020-03-17 half way through pcb layout v6
    [drumkid.kicad_pcb, drumkid.sch]
2020-03-17 some decent pcb progress
    [drumkid.kicad_pcb, drumkid.sch]
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2020-03-18 about to start routing
    [drumkid.kicad_pcb]
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2020-03-18 re-added reverse to mozziDK
    [MozziGuts.cpp, TimerOne.h]
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2020-03-25 finalised parameter labels on pcb
    [drumkid.kicad_pcb]
2020-03-25 drumkid v6 prototype pcb ordered!
    [_saved_drumkid.sch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]
2020-03-25 oops forgot to save some stuff
    [_saved_drumkid.sch, drumkid.sch]
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2020-06-29 after much faffing, the tap tempo function is still broken but in a better way
    [drumkid.ino]
2020-07-02 CC input works but glitchy when used with sync
    [drumkid.ino]
2020-07-03 bigger drone dead zone, reset function, random session function
    [drumkid.ino]
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2020-07-07 quick fix to remove external dependencies
    [MozziGuts.cpp, TimerOne.h, drumkid.ino]
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2020-07-07 sample tool starting to work properly, need to fix naming
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2020-07-20 quick fix for issue with firmware 1.2
    [drumkid.ino]
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2020-07-22 reversed LED colours
2020-08-03 another new PCB revision, hopefully the last one for a while...
    [drumkid-B_Cu.gbr, drumkid-B_Mask.gbr, drumkid-B_Paste.gbr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]
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2020-08-03 may have squeezed too many things onto the PCB...
    [drumkid.kicad_pcb, drumkid.sch]
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2020-08-04 omg that's the best routing i've ever done
    [drumkid.kicad_pcb]
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2020-08-04 sorry i keep committing to the master branch, this is the last time!
    [breadboard.fzz]
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2021-01-26 oops forgot to to commit for a while
    [breadboard.fzz]
2021-01-26 fixed breadboard error
    [breadboard.fzz]
2021-08-19 little manual update and new PCB in progress
    [drumkid.kicad_pcb, drumkid.sch]
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2023-02-17 about to update to kicad 7, fingers crossed
    [drumkid.kicad_pcb, drumkid.kicad_sch]
